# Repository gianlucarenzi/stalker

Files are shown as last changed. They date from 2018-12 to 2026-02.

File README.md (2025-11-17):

STm32-to-Amiga-Local-Keyboard adaptER
=====================================

The STALKER adapter board enables connecting USB HID keyboards to your Amiga 1000, Amiga 2000/3000, Amiga 4000/CD32, Amiga 500, Amiga 1200 and Amiga 600 and it is based upon 32-bit STM32 microcontroller.

The STALKER provides built-in USB stack which enables USB HID keyboards support without the need for installing additional AmigaOS software drivers. The whole installation process comes down to simply connecting a STALKER adapter and plug to the keyboard port of your Amiga 1000, 2000 or 4000 externally, or internally in any other Amiga computers.

Additional feature of the adapter is its „Bootloader” function allowing future firmware upgrades.
The STALKER comes with dedicated firmware, but it can be easily installed any firmware version as it's an open source project.

Features
========

* supports for both USB HID, wireless adapters and USB-PS/2 keyboards,
* Amiga 1000, 2000/3000, Amiga 4000/CD32, Amiga 1200, Amiga 600 and Amiga 500 compatibility,
* built-in USB stack with HID Keyboard firmware driver
* "Bootloader" function allowing future firmware upgrades,
* "Status" indicator LED providing information about device's state,
* built around 32-bit STM32 microcontroller utilizing latest technology,
* non-blocking keyboard.

Why so a bad name for a so good product?

As stated in the title, the STALKER is an acronym of:

STm32-to-Amiga-Local-Keyboard adaptER
-------------------------------------

But if you think a little more, it is catching all the keystrokes you do,

so basically it is stalking you! ;-)

Rendered Images
---------------
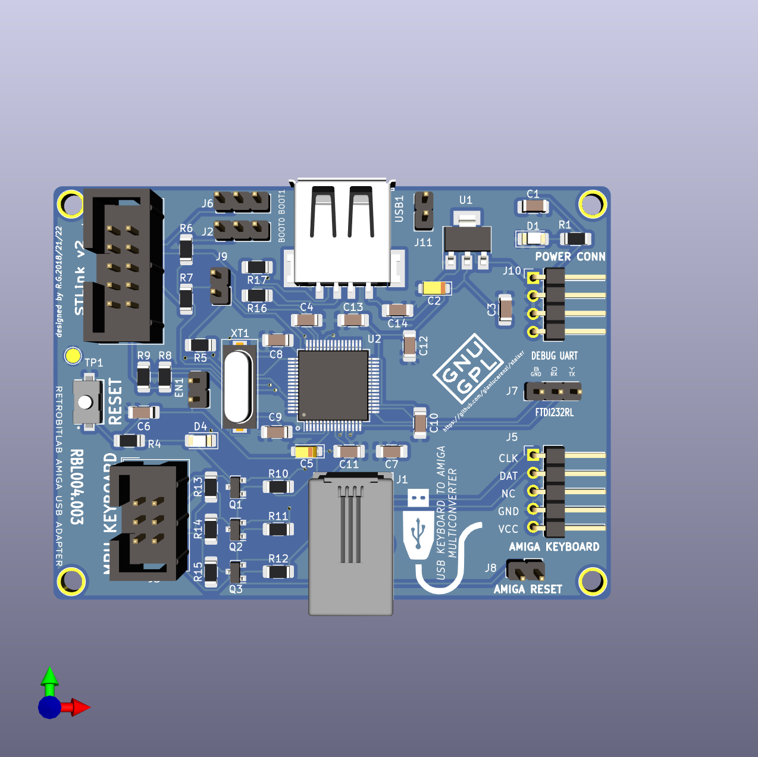
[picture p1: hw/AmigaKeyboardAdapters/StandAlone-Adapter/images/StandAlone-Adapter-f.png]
Board Front

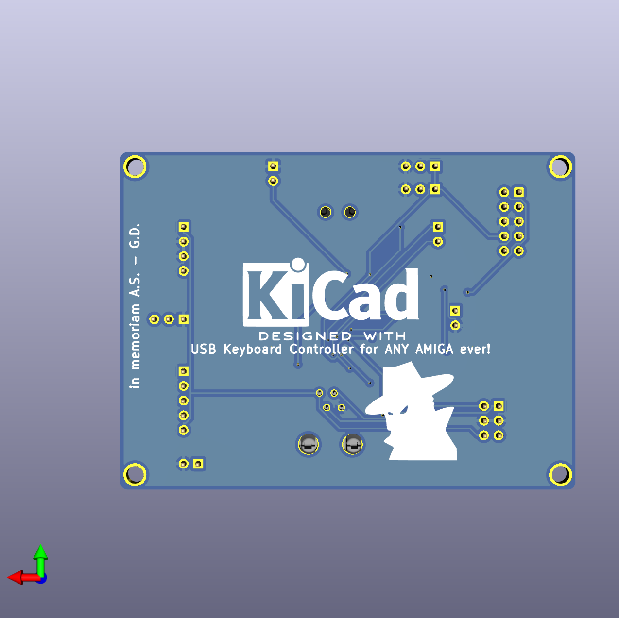
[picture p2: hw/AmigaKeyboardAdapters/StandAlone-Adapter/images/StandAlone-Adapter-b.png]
Board Back

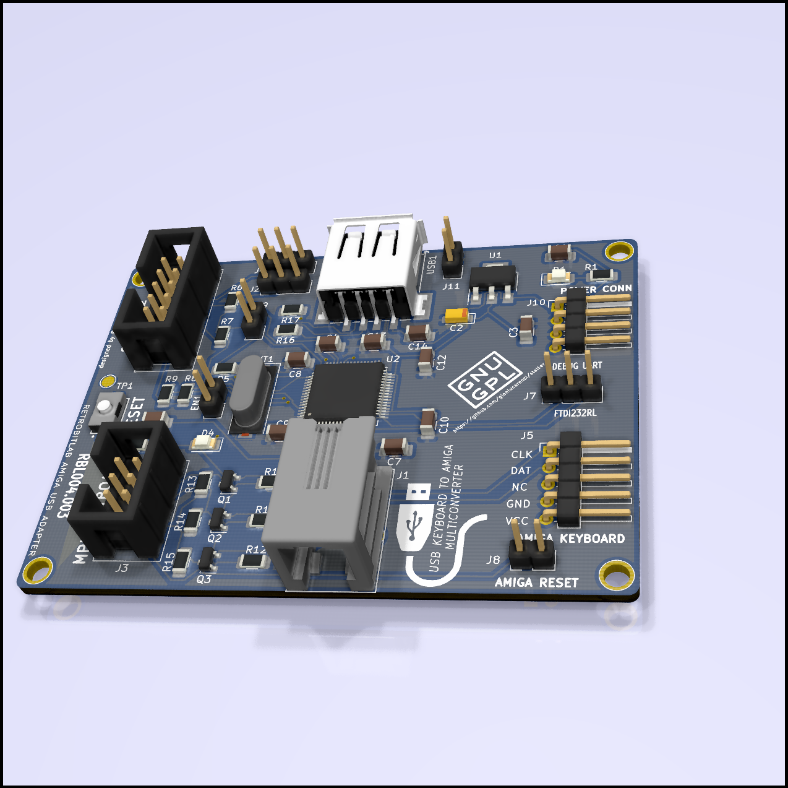
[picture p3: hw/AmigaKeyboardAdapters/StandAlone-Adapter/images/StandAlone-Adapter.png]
Board Overall


Upgrading with Linux and OpenOCD and STLinkV2 Programmer/Debugger
-----------------------------------------------------------------
Starting from this project folder, there are some shell scripts
that can be used to program the board if you unluckly brick it or simply to upgrade
some features from bootloader and application without using the STM32CubeProgrammer software.

Connect the [STLinkV2 jtag/swd programmer](https://it.aliexpress.com/item/1005005293861493.html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)
to the STALKER Board in J4 connector (STLink V2 in the silkscreen) using a standard 10 pin IDC female/female [cable 2x5 10P](https://it.aliexpress.com/item/1005003161799870.html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).
Opening the project folder, you can compile all projects (application and bootloader) running:
```
make clean
make
```
and then launch the corresponding script:

* bootloader.sh (to erase all the flash memory and program the bootloader)

* flash.sh (to program the application, after having erased all needed flash sectors)

Upgrading quick guide
---------------------
First, get your own copy of STM32CubeProgrammer software.
It is free to use, please checkout the STMicroElectronics web site and install it into your PC.
Please have a look at the following web link: https://www.st.com/en/development-tools/stm32cubeprog.html

After launched it will be shown as the following image.



Connect the <b>special upgrade cable</b> to the right lower opening of <b>The STALKER</b>, then connect the board with the provided USB cable to the one of the USB ports available in your computer. The red LED will light steady.

Then click on the connect button on the upper right position of the STM32Cube Programmer's window as shown in the picture below:

pic1-connect

Some information will be shown into the right bottom side of the same window, plus the memory locations will be filled up by the programmed values.

pic2-connected

After, you will need to select the correct <b>FIRMWARE</b> file (<b>.hex file format</b>) clicking into the <b>Open File</b> tab button like in the following example:

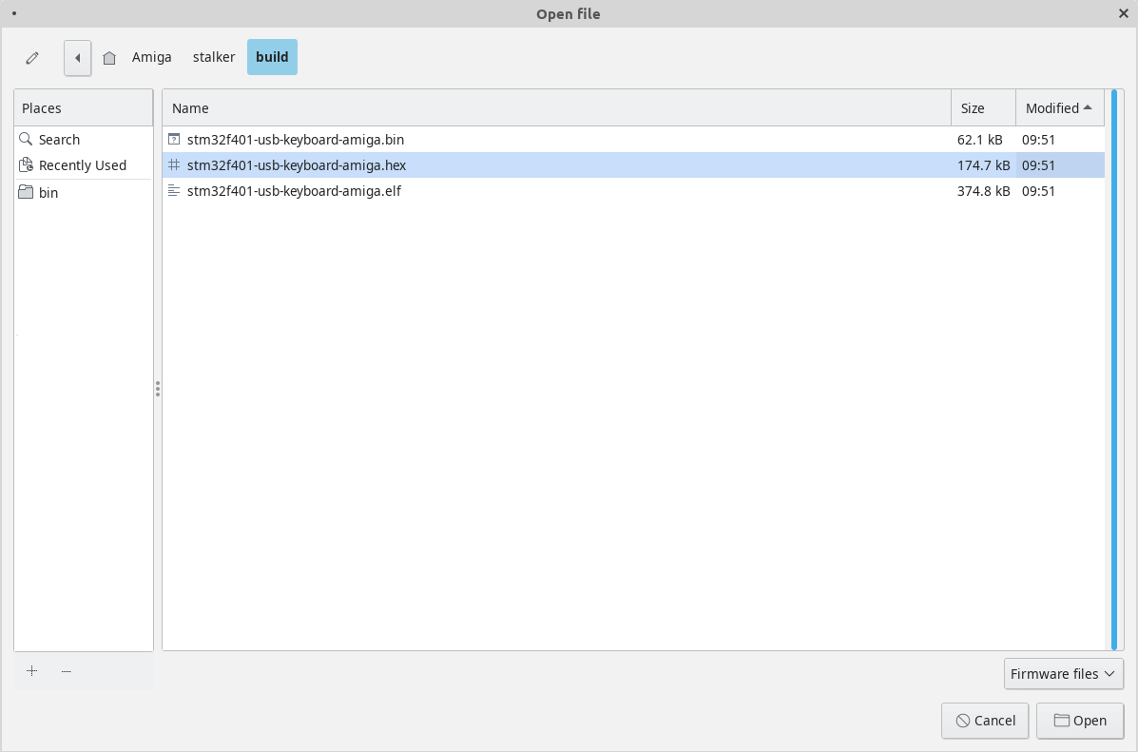
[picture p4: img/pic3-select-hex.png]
pic3-select-hex


If the file is loaded correctly, the <b>Download button</b> needs to be pressed to start the programming/flashing procedure. It will takes few seconds to be completed.

pic4-download-flash

The firmware is correctly installed into the board, and it can be used as usual.

pic5-complete

Now you can:

* Disconnect the board from USB from your PC
* Remove the special ugrade cable
* Re-install the board into your Amiga Computer's setup.
* Connect a USB Keyboard, and turn on the Amiga Computer.

That's all folks!

Software & Hardware License
---------------------------
Copyright (C) 2018/2019/2022/2023/2025 Gianluca Renzi <gianlucarenzi@eurek.it> <icjtqr@gmail.com>

The hardware of this project is released as free/open hardware under the
GNU GPL v3 License terms. See licence.txt for details.

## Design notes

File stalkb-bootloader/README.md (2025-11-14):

# STM32 USB Bootloader

This project implements a simple USB bootloader for STM32F401xC microcontrollers. It allows for in-application firmware updates via USB.

## Features

*   **Custom Bootloader:** Provides a mechanism to jump to either the DFU (Device Firmware Upgrade) bootloader or a user application.
*   **Boot Mode Selection:** Determines whether to enter DFU mode or run the application based on a GPIO pin state.
*   **Application Validation:** Checks the validity of the application firmware before jumping to it.
*   **UART Output:** Provides informative messages via UART for debugging and status updates.

## Getting Started

These instructions will get you a copy of the project up and running on your local machine for development and testing purposes.

### Prerequisites

*   **ARM GCC Compiler:** You will need an ARM-none-eabi toolchain.
    *   For Debian/Ubuntu: `sudo apt-get install gcc-arm-none-eabi`
*   **Make:** Build automation tool.
    *   For Debian/Ubuntu: `sudo apt-get install make`
*   **STM32CubeIDE or equivalent:** For project configuration and initial code generation (though this project is already configured).

### Building the Project

To build the project, navigate to the root directory of the repository and run `make`:

```bash
make
```

This will generate the `.elf`, `.hex`, and `.bin` files in the `build/` directory.

### Flashing the Bootloader

The generated `.bin` or `.hex` file can be flashed to your STM32F401xC microcontroller using an ST-Link debugger or similar programming tool.

### Usage

1.  **Power on** your STM32F401xC board.
2.  The bootloader will check the state of the `BOOT_MODE_Pin` (configured in `main.c` and `MX_GPIO_Init`).
    *   If `BOOT_MODE_Pin` is **LOW**, the bootloader will jump to the **DFU Bootloader**.
    *   If `BOOT_MODE_Pin` is **HIGH**, the bootloader will attempt to jump to the **user application**.
3.  Ensure your user application is flashed at the correct address (defined by `__appflash_start` in the linker script).

## Project Structure

*   `Core/`: Contains application-specific source code and headers (`main.c`, `stm32f4xx_it.c`, etc.).
*   `Drivers/`: Contains STM32 HAL drivers and CMSIS files.
*   `STM32F401XX_FLASH.ld`: Linker script for the STM32F401xC.
*   `Makefile`: Build script for the project.
*   `startup_stm32f401xc.s`: Startup assembly file.

## Contributing

Feel free to fork the repository, open issues, or submit pull requests.

## License

This project is licensed under the terms found in the `LICENSE` file in the root directory of this software component.

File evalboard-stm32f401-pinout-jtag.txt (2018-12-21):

EVALBOARD ARMJTAG PINOUT
------------------------

HEADER_CONN_2X10

1  +3v3       2   +3v3
3  nTRST      4   GND
5  TDI        6   GND
7  TMS/SWDIO  8   GND
9  TCK/SWCLK  10  GND
11 NC         12  GND
13 TDO        14  GND
15 nRST       16  GND
17 NC         18  GND
19 NC         20  GND

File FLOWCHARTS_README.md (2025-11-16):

# Project Flowcharts - USB to Amiga Keyboard Adapter

Questo documento descrive i diagrammi di flusso del progetto **USB to Amiga Keyboard Adapter** basato su FreeRTOS.

## 📊 Diagrammi Disponibili

### 1. **Project Flowchart** (`project_flowchart.svg/png`)
**Panoramica generale dell'architettura del progetto**

- **Scopo**: Mostra la struttura generale del sistema con tutti i componenti principali
- **Livelli mostrati**:
  - Hardware Layer (USB Keyboard, STM32F401, Amiga Computer)
  - FreeRTOS Kernel (Scheduler, Code)
  - Application Tasks (USB Task, Amiga Task)
  - Hardware Abstraction Layer (Driver STM32)
  - System Initialization (main, init)

### 2. **Detailed Architecture** (`detailed_architecture.svg/png`)
**Architettura dettagliata con flusso dati**

- **Scopo**: Mostra il flusso dettagliato dei dati tra i componenti
- **Dettagli inclusi**:
  - Strutture dati (keyboard_message_t, led_message_t)
  - Timing dei task (10ms per tutti i task principali)
  - Priorità dei task (USB=Normal, Amiga=Low, LedManager=Low)
  - Dettagli del protocollo Amiga
  - Dimensioni delle code FreeRTOS

### 3. **Timing Flow** (`timing_flow.svg/png`)
**Flusso temporale delle operazioni**

- **Scopo**: Mostra la sequenza temporale delle operazioni del sistema
- **Sezioni**:
  - Sequenza di startup del sistema
  - Cicli runtime dei task
  - Timing del protocollo Amiga (livello microsecondo)
  - Gestione degli errori
  - Annotazioni temporali precise

## 🎯 **Architettura FreeRTOS**

### **Task Principali**

| Task | Priorità | Ciclo | Stack | Responsabilità |
|---|---|---|---|---|
| **USB Task** | Normal | 10ms | 1024 | USB HID, LED, Stato connessione |
| **Amiga Task** | Low | 10ms | 1024 | GPIO, Protocollo Amiga, Reset |
| **LedManagerTask** | Low | Event-Driven | 512 | Gestione LED di stato onboard |

### **Comunicazione Inter-Task**

| Coda | Dimensione | Direzione | Contenuto |
|---|---|---|---|
| **keyboardQueue** | 16 messaggi | USB → Amiga | keyboard_message_t |
| **ledQueue** | 16 messaggi | Amiga → USB | led_message_t |
| **ledManagerQueue**| 32 messaggi | USB → LedManager| led_manager_message_t |
| **amigaTaskQueue** | 8 messaggi | All → Amiga | AmigaTaskMsg_t |

### **Timing Critici**

| Operazione | Timing | Descrizione |
|---|---|---|
| **USB Task Cycle** | 10ms | Ciclo principale USB task |
| **Amiga Task Cycle** | 10ms | Ciclo principale Amiga task |
| **Clock Pulse** | 20μs | Durata impulso clock Amiga |
| **Handshake** | 85μs | Impulso handshake CPU Amiga |
| **Reset Detection** | 500ms | Timeout per rilevamento reset |

## 🔧 **Protocollo Amiga**

### **Caratteristiche Principali**
- **Ordine bit**: 6-5-4-3-2-1-0-7 (bit 7 = flag up/down)
- **Logica invertita**: 0 = HIGH (5V), 1 = LOW (0V)
- **Velocità**: ~17 kbits/sec (60μs per bit)
- **Handshake**: Obbligatorio impulso 85μs da CPU

### **Sequenza Trasmissione**
1. Setup data line (20μs)
2. Clock pulse LOW (20μs)
3. Clock pulse HIGH (20μs)
4. Ripeti per 8 bit
5. Attendi handshake CPU (85μs)

## 🚀 **Flusso di Esecuzione**

### **Startup Sequence**
1. `HAL_Init()` - Inizializzazione HAL
2. `SystemClock_Config()` - Configurazione clock
3. `MX_GPIO_Init()` - Inizializzazione GPIO
4. `MX_USART2_UART_Init()` - Inizializzazione UART debug
5. `create_tasks_and_queues()` - Creazione task e code
6. `vTaskStartScheduler()` - Avvio scheduler FreeRTOS

### **Runtime Operation**
- **USB Task**: Gestisce USB HID e LED ogni 10ms
- **Amiga Task**: Processa tastiera e gestisce reset ogni 10ms
- **Comunicazione**: Via code FreeRTOS thread-safe

## 📁 **File Generati**

```
project_flowchart.dot       # Sorgente Graphviz - Panoramica generale
project_flowchart.svg       # Diagramma SVG - Panoramica generale  
project_flowchart.png       # Diagramma PNG - Panoramica generale

detailed_architecture.dot   # Sorgente Graphviz - Architettura dettagliata
detailed_architecture.svg   # Diagramma SVG - Architettura dettagliata
detailed_architecture.png   # Diagramma PNG - Architettura dettagliata

timing_flow.dot             # Sorgente Graphviz - Flusso temporale
timing_flow.svg             # Diagramma SVG - Flusso temporale
timing_flow.png             # Diagramma PNG - Flusso temporale
```

## 🛠️ **Rigenerazione Diagrammi**

Per rigenerare i diagrammi:

```bash
# SVG (vettoriale)
dot -Tsvg project_flowchart.dot -o project_flowchart.svg
dot -Tsvg detailed_architecture.dot -o detailed_architecture.svg  
dot -Tsvg timing_flow.dot -o timing_flow.svg

# PNG (alta risoluzione)
dot -Tpng project_flowchart.dot -o project_flowchart.png -Gdpi=300
dot -Tpng detailed_architecture.dot -o detailed_architecture.png -Gdpi=300
dot -Tpng timing_flow.dot -o timing_flow.png -Gdpi=300
```

## 📋 **Note**

- I diagrammi sono ottimizzati per la documentazione tecnica
- I colori identificano i diversi livelli architetturali
- Le frecce tratteggiate indicano connessioni hardware
- Le frecce punteggiate indicano timing/cicli
- I diagrammi sono scalabili (formato SVG disponibile)

---
**Generato automaticamente per il progetto USB to Amiga Keyboard Adapter v3.0NG-RTOS**

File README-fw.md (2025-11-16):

# StalkerNG - Amiga Keyboard Interface Firmware

## Project Overview

This project provides firmware for an STM32F401xC microcontroller, designed to bridge modern USB keyboards with classic Amiga computers. It acts as an intelligent interface, translating standard USB Human Interface Device (HID) keyboard inputs into the specific Amiga keyboard protocol. This enables Amiga users to utilize a wide range of contemporary USB keyboards with their vintage systems, enhancing usability without compromising the authentic Amiga experience.

The firmware incorporates advanced features such as dynamic mode switching between Amiga and PC keyboard layouts, comprehensive LED status management (Caps Lock, Num Lock, Scroll Lock), and robust system reset functionalities triggered by specific key combinations or Amiga hardware signals. Built upon the FreeRTOS real-time operating system, it ensures efficient and concurrent management of all tasks, from USB communication to Amiga protocol handling and persistent settings storage.

## Features

*   **Firmware Version:** `v3.0NG-RTOS`
*   **USB HID Keyboard Host:** Full support for connecting and interpreting inputs from standard USB HID keyboards.
*   **Amiga Keyboard Protocol Translation:** Seamless conversion of USB keyboard events into the native Amiga keyboard protocol.
*   **Dynamic Mode Switching:** Toggle between Amiga and PC keyboard layouts using a dedicated key combination (`Left Control + Left Alt + Left Shift + P`). The selected mode is persistently stored in EEPROM.
*   **LED Status Synchronization:** Synchronizes Caps Lock, Num Lock, and Scroll Lock LED states between the USB keyboard and the Amiga system.
*   **System Reset Functionality:**
    *   **PC Mode Reset:** Triggered by holding `Control + Alt + Delete` for 500ms.
    *   **Amiga Mode Reset:** Triggered by holding `Left Control + Left GUI + (Right GUI or Application Key)` for 500ms.
    *   Supports hardware-initiated resets from the Amiga side.
*   **Persistent Settings:** Utilizes internal EEPROM (or Flash emulation) for storing user preferences, such as the last selected operating mode.
*   **Real-Time Operating System (RTOS):** Leverages FreeRTOS for efficient multi-tasking, ensuring responsive and reliable operation.
*   **Easter Egg:** If no keyboard is connected, the firmware will periodically type out a message on the Amiga. This feature is enabled by a compile-time flag.

## Hardware Requirements

*   **Microcontroller:** STM32F401xC (or any compatible STM32F4 series board with USB Host capabilities).
*   **USB Host Port:** Required for connecting USB keyboards.
*   **Amiga Interface Circuitry:** Custom hardware interface to connect the microcontroller to the Amiga keyboard port.

## Software Architecture

The firmware is structured around the STM32Cube HAL and FreeRTOS, providing a robust and modular foundation. A multi-tasking paradigm is employed to manage various functionalities concurrently, ensuring high responsiveness and system stability.

*   **FreeRTOS:** The core of the concurrent execution, managing task scheduling, inter-task communication (via message queues), and precise timing.
*   **STM32 HAL Drivers:** Provides low-level access and control over the STM32 microcontroller's peripherals.
*   **USB Host Library:** Handles the complexities of USB communication, including device enumeration, configuration, and parsing of HID reports from connected keyboards.
*   **Amiga Keyboard Protocol Driver:** Implements the specific timing and data exchange required for communication with the Amiga computer, translating generic USB HID scancodes into Amiga-specific scancodes.
*   **EEPROM Driver:** Manages read and write operations to non-volatile memory, ensuring that user settings and configurations persist across power cycles.
*   **Inter-Task Communication:** Tasks communicate using thread-safe FreeRTOS queues:
    *   `keyboardQueueHandle`: Passes raw keyboard data from `usbTask` to `amigaTask`.
    *   `ledQueueHandle`: Passes LED status changes (Caps/Num/Scroll lock) from `amigaTask` to `usbTask`.
    *   `ledManagerQueueHandle`: Sends commands from `usbTask` to `led_manager_task` to control the onboard status LED.
    *   `amigaTaskQueueHandle`: Used for sending internal commands (like reset notifications) to the `amigaTask` itself.

## Key Components (FreeRTOS Tasks)

The firmware is organized into several FreeRTOS tasks, each responsible for a specific aspect of the system:

### `amigaTask`

This task is the central hub for Amiga-related keyboard logic. Its priority is `osPriorityLow`.

*   **Initialization:** Sets up the Amiga keyboard interface and reads the initial operating mode from EEPROM.
*   **Mode Management:** Determines and sets the `current_mode` (AMIGA_MODE or PC_MODE) based on saved settings or defaults.
*   **Event Processing:** Receives `keyboard_message_t` events from the `usbTask` via `keyboardQueueHandle`.
*   **Protocol Translation:** Converts received USB HID data into the Amiga keyboard protocol and sends it to the Amiga via `amikb_process()`.
*   **Mode Switching:** Detects and acts upon the `Left Control + Left Alt + Left Shift + P` key combination to toggle operating modes.
*   **System Reset Handling:** Monitors for specific key combinations (`Control + Alt + Delete` in PC mode, `Left Control + Left GUI + (Right GUI or Application Key)` in Amiga mode) and Amiga hardware reset signals, initiating a system reset if conditions are met.
*   **LED Feedback:** Sends `led_status_t` updates to the `ledQueueHandle` for visual feedback.

#### `amigaTask` Main Loop Flowchart

```mermaid
graph TD
    A[Start amigaTask] --> B{Initialize Amiga Interface};
    B --> C{Read Mode from EEPROM};
    C --> D{Set current_mode};
    D --> E[amiga_task_init()];
    E --> F[Loop Forever];
    F --> G{osMessageQueueGet(keyboardQueueHandle, msg, 0)};
    G -- osOK --> H{process_keyboard_message(msg)};
    H --> I{convert_message_to_keyboard_code(msg, code)};
    I --> J{amikb_process(code)};
    J --> K{Check if Amiga Interface is ready};
    K -- Not Ready --> L[Set amiga_ready = 1; amikb_ready(1)];
    L --> M{osMessageQueueGet(amigaTaskQueueHandle, internal_msg, 0)};
    G -- Not osOK --> M;
    M -- osOK (RESET_START) --> N[Send LED_RESET_BLINK to ledQueue];
    N --> O[check_for_special_combos()];
    M -- Not osOK --> O;
    O --> P[amiga_task_check_reset_condition()];
    P --> Q[osDelay(10ms)];
    Q --> F;
```

**Timing Considerations for `amigaTask`:**
*   `osMessageQueueGet(keyboardQueueHandle, ..., 0)`: This is a non-blocking call, ensuring the task doesn't halt waiting for keyboard input. Keyboard events are processed as soon as they are available.
*   `osMessageQueueGet(amigaTaskQueueHandle, ..., 0)`: Also non-blocking, for internal task communication.
*   `osDelay(10ms)`: A small delay introduced at the end of the loop to yield CPU time to other tasks and prevent busy-waiting. This results in a cycle time of approximately 10ms.
*   `check_for_special_combos()` and `amiga_task_check_reset_condition()`: Both functions incorporate internal timers (e.g., `RESET_TIMEOUT_MS` of 500ms) to detect sustained key presses or Amiga clock line states, preventing spurious triggers.

### `usbTask`

Responsible for all USB Host related operations, primarily interacting with USB keyboards. Its priority is `osPriorityNormal`.

*   **USB Host Management:** Initializes and manages the USB Host stack.
*   **Device Detection:** Monitors for the connection and disconnection of USB keyboards.
*   **HID Report Processing:** Reads raw HID reports from connected keyboards, sending an update only when the state changes.
*   **Event Generation:** Parses HID data into a structured `keyboard_message_t` format.
*   **Inter-Task Communication:** Sends processed keyboard messages to the `amigaTask` via `keyboardQueueHandle`.
*   **LED Control:** Receives `led_status_t` commands from the `amigaTask` and controls the LEDs on the connected USB keyboard (e.g., Caps Lock, Num Lock).

#### `usbTask` Main Loop Flowchart (Conceptual)

```mermaid
graph TD
    A[Start usbTask] --> B{Initialize USB Host};
    B --> C[Loop Forever];
    C --> D{USBH_Process()};
    D --> E{Check for USB Keyboard State Changes};
    E -- Connected --> F{Read HID Report};
    F --> G{Parse HID Data & Check for Changes};
    G -- State Changed --> H{Create keyboard_message_t};
    H --> I{osMessageQueuePut(keyboardQueueHandle, msg, 0)};
    I --> J{Check for LED Status Messages};
    J -- osOK --> K{Control USB Keyboard LEDs};
    K --> C;
    J -- Not osOK --> C;
    G -- No Change --> J;
    E -- Disconnected --> L[Send Reset Event to amigaTask];
    L --> C;
```

**Timing Considerations for `usbTask`:**
*   `USBH_Process()`: This function is the core of the USB host stack and is called in a loop.
*   `osDelay(10ms)`: The task loop has a 10ms delay, making it responsive to USB events and LED control messages.
*   HID Report Polling: The frequency of reading HID reports is often dictated by the USB HID descriptor of the connected keyboard (e.g., 8ms, 10ms). The `usbTask`'s loop is fast enough to accommodate this polling rate.
*   `osMessageQueuePut(keyboardQueueHandle, msg, 0, 0)`: A non-blocking call to send keyboard events, ensuring the `usbTask` doesn't block if the `amigaTask` queue is temporarily full.

### `eeprom_task`

Manages non-volatile storage operations.

*   **Persistence:** Handles asynchronous read and write requests for system settings (e.g., `current_mode`) to the internal EEPROM (emulated in Flash).
*   **Reliability:** Ensures data integrity during storage operations.

### `led_manager_task`

Controls the onboard status LED for visual feedback. Its priority is `osPriorityLow`.

*   **LED Control:** Receives commands via `ledManagerQueueHandle` from other tasks (like `usbTask`) and manages the state of the single onboard LED to reflect system status (e.g., solid ON for ready, blinking for waiting).

### `log_task`

Handles system logging and debugging output.

*   **Debug Output:** Processes and outputs debug messages generated by other tasks, typically via a UART interface to a connected terminal or debug probe. It is initialized at startup but does not run as a separate task.

## Build Instructions

The project uses a standard GNU Make-based build system.

1.  **Toolchain:** Ensure you have the `arm-none-eabi-gcc` toolchain installed and configured in your system's PATH.
2.  **Navigate:** Open a terminal and navigate to the root directory of this project.
3.  **Clean Build:** To remove all previously compiled files and artifacts, execute:
    ```bash
    make clean
    ```
4.  **Build Firmware:** To compile the source code and link the final firmware image, execute:
    ```bash
    make
    ```
5.  **Output:** Upon successful compilation, the following files will be generated in the `build/` directory:
    *   `StalkerNG.elf`: Executable and Linkable Format (ELF) file, containing debugging information.
    *   `StalkerNG.hex`: Intel HEX format file, commonly used for flashing.
    *   `StalkerNG.bin`: Raw binary image, also suitable for flashing.

## Usage and Operation

1.  **Flash Firmware:** Program the `StalkerNG.bin` file onto your STM32F401xC development board using your preferred flashing tool (e.g., STM32CubeProgrammer, OpenOCD).
2.  **Connect USB Keyboard:** Plug your USB keyboard into the USB Host port on the STM32 board.
3.  **Connect to Amiga:** Connect the custom Amiga interface from your STM32 board to the keyboard port of your Amiga computer.
4.  **Power On:** Power on your STM32 board and Amiga.

### Mode Switching

The firmware supports two operating modes: Amiga Mode and PC Mode.

*   **Toggle Mode:** Press and hold the key combination `Left Control + Left Alt + Left Shift + P`. The mode will toggle between AMIGA_MODE and PC_MODE.
*   **Persistence:** The selected mode is automatically saved to the internal EEPROM and will be restored on subsequent power-ups.

### System Reset

The firmware provides multiple ways to trigger a system reset for the Amiga.

*   **PC Mode Reset:** While in PC Mode, press and hold `Control + Alt + Delete` for approximately 500 milliseconds.
*   **Amiga Mode Reset:** While in Amiga Mode, press and hold `Left Control + Left GUI + (Right GUI or Application Key)` for approximately 500 milliseconds.
*   **Amiga Hardware Reset:** The firmware also detects and responds to a hardware-initiated reset signal from the Amiga computer itself.

### USB Keyboard Compatibility

It is crucial to understand that **not all USB keyboards are compatible** with this firmware. The compatibility depends on how the keyboard communicates its key presses to the host.

This firmware, due to limitations in the underlying STM32 USB Host HID drivers, primarily supports keyboards that operate using the **USB HID Boot Protocol**. This protocol is a simplified subset of the full HID specification, designed to provide basic keyboard (and mouse) functionality even before a full operating system driver is loaded.

Keyboards that rely on the more complex **USB HID Report Protocol** for their functionality (especially those with advanced features, custom layouts, or extensive multimedia keys) are generally **not supported**. The firmware's current HID implementation is not adequate to fully interpret these custom report descriptors.

**What to look for in a compatible keyboard:**

*   **Basic Functionality:** Keyboards designed for general office use or older systems are more likely to implement the Boot Protocol.
*   **Simplicity:** Keyboards without extensive programmable keys, RGB lighting, or complex multimedia functions beyond standard volume/play controls might be more compatible.
*   **Testing is Key:** The best way to determine compatibility is often to test the keyboard with the firmware.

**Known Compatible Example:**

*   **Logitech Wireless Keyboards with Unifying Receiver (e.g., VID 0x046d, PID 0xc534):** Many Logitech wireless keyboard/mouse combinations that use the Unifying Receiver dongle operate in USB BOOT mode for basic functionality.
    *   **Note:** While the basic alphanumeric and modifier keys typically work, **multimedia keys** (e.g., volume, play/pause) on such keyboards are often implemented using the HID Report Protocol and may **not be recognized** by this firmware.

We recommend users to prioritize keyboards known for their basic, robust USB HID compliance. If a keyboard does not work, it is likely due to its reliance on the USB HID Report Protocol.

## Contributing

Contributions are welcome! If you find a bug or have an enhancement in mind, please open an issue or submit a pull request.

## License

This project is licensed under the terms found in the `LICENSE` file in the root directory of this repository.

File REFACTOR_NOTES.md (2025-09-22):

# FreeRTOS Refactor - USB to Amiga Keyboard Adapter

## Overview

This document describes the refactoring of the USB to Amiga keyboard adapter project to use FreeRTOS with two separate tasks for better separation of concerns and improved real-time performance.

## Architecture Changes

### Before Refactor
- Single main loop handling both USB and Amiga communication
- Blocking operations and polling-based approach
- Tight coupling between USB and Amiga logic

### After Refactor
- Two separate FreeRTOS tasks:
  - **usb_task**: Handles USB HID protocol and LED management
  - **amiga_task**: Handles GPIO communication with Amiga and scancode processing
- Queue-based communication between tasks
- Non-blocking, event-driven architecture

## Task Structure

### USB Task (`usb_task`)
**Priority**: 3 (High)
**Stack Size**: 512 words (configMINIMAL_STACK_SIZE * 4)
**Responsibilities**:
- Initialize and manage USB Host
- Process USB HID events
- Handle keyboard connection/disconnection
- Read keyboard data from USB
- Manage USB keyboard LEDs
- Send keyboard data to Amiga task via queue
- Receive LED commands from Amiga task via queue

**Key Functions**:
- `usb_task()` - Main task function
- `usb_task_init()` - Task initialization
- `usb_keyboard_led_set()` - Set keyboard LED state
- `usb_keyboard_led_init_sequence()` - LED initialization sequence

### Amiga Task (`amiga_task`)
**Priority**: 2 (Medium)
**Stack Size**: 256 words (configMINIMAL_STACK_SIZE * 2)
**Responsibilities**:
- Initialize Amiga GPIO interface
- Process keyboard data from USB task
- Convert USB scancodes to Amiga scancodes
- Handle Amiga keyboard protocol timing
- Manage Amiga reset conditions
- Send LED status updates to USB task

**Key Functions**:
- `amiga_task()` - Main task function
- `amiga_task_init()` - Task initialization
- `amiga_task_handle_reset()` - Handle Amiga reset sequence

## Communication

### Queues
Two FreeRTOS queues handle inter-task communication:

1. **keyboard_queue** (USB → Amiga)
   - Size: 10 messages
   - Type: `keyboard_message_t`
   - Contains: keyboard data + timestamp

2. **led_queue** (Amiga → USB)
   - Size: 5 messages
   - Type: `led_message_t`
   - Contains: LED status + timestamp

### Message Structures
```c
typedef struct {
    keyboard_code_t keycode;
    uint32_t timestamp;
} keyboard_message_t;

typedef struct {
    led_status_t led_status;
    uint32_t timestamp;
} led_message_t;
```

## Files Added

### Header Files
- `inc/task_communication.h` - Common definitions for task communication
- `inc/usb_task.h` - USB task interface
- `inc/amiga_task.h` - Amiga task interface

### Source Files
- `src/usb_task.c` - USB task implementation
- `src/amiga_task.c` - Amiga task implementation

### Modified Files
- `src/main.c` - Refactored to create tasks and start scheduler
- `Makefile` - Added new source files

## Benefits of Refactor

1. **Separation of Concerns**: USB and Amiga logic are now completely separate
2. **Better Real-time Performance**: High-priority USB task ensures responsive USB handling
3. **Improved Maintainability**: Each task has a clear, focused responsibility
4. **Scalability**: Easy to add new features or modify individual components
5. **Debugging**: Easier to debug issues in specific subsystems
6. **Resource Management**: Better control over stack usage and CPU time

## Timing Considerations

- USB task runs at 10ms intervals for responsive USB handling
- Amiga task runs at 50ms intervals for reset condition checking
- Critical Amiga timing (20μs, 85μs) still uses hardware delays (udelay)
- FreeRTOS tick rate: 1ms (1000 Hz)

## Memory Usage

- **Total heap size**: 17KB (configTOTAL_HEAP_SIZE)
- **USB task stack**: ~2KB
- **Amiga task stack**: ~1KB
- **Queue memory**: ~500 bytes total
- **Remaining heap**: ~13.5KB for other allocations

## Configuration

Key FreeRTOS configuration parameters in `FreeRTOSConfig.h`:
- `configTICK_RATE_HZ`: 1000 (1ms tick)
- `configMAX_PRIORITIES`: 5
- `configTOTAL_HEAP_SIZE`: 17KB
- `configUSE_PREEMPTION`: 1 (preemptive scheduling)

## Future Enhancements

Possible future improvements:
1. Add watchdog task for system monitoring
2. Implement power management features
3. Add configuration task for runtime settings
4. Implement USB device detection improvements
5. Add statistics collection task

## Testing Notes

When testing the refactored code:
1. Verify USB keyboard detection and LED functionality
2. Test Amiga reset sequence
3. Check for proper task scheduling and no deadlocks
4. Verify timing-critical Amiga protocol operations
5. Test under various load conditions

## Compatibility

The refactored code maintains full compatibility with:
- Original hardware design
- Amiga keyboard protocol
- USB HID keyboard standard
- All existing features and Easter eggs

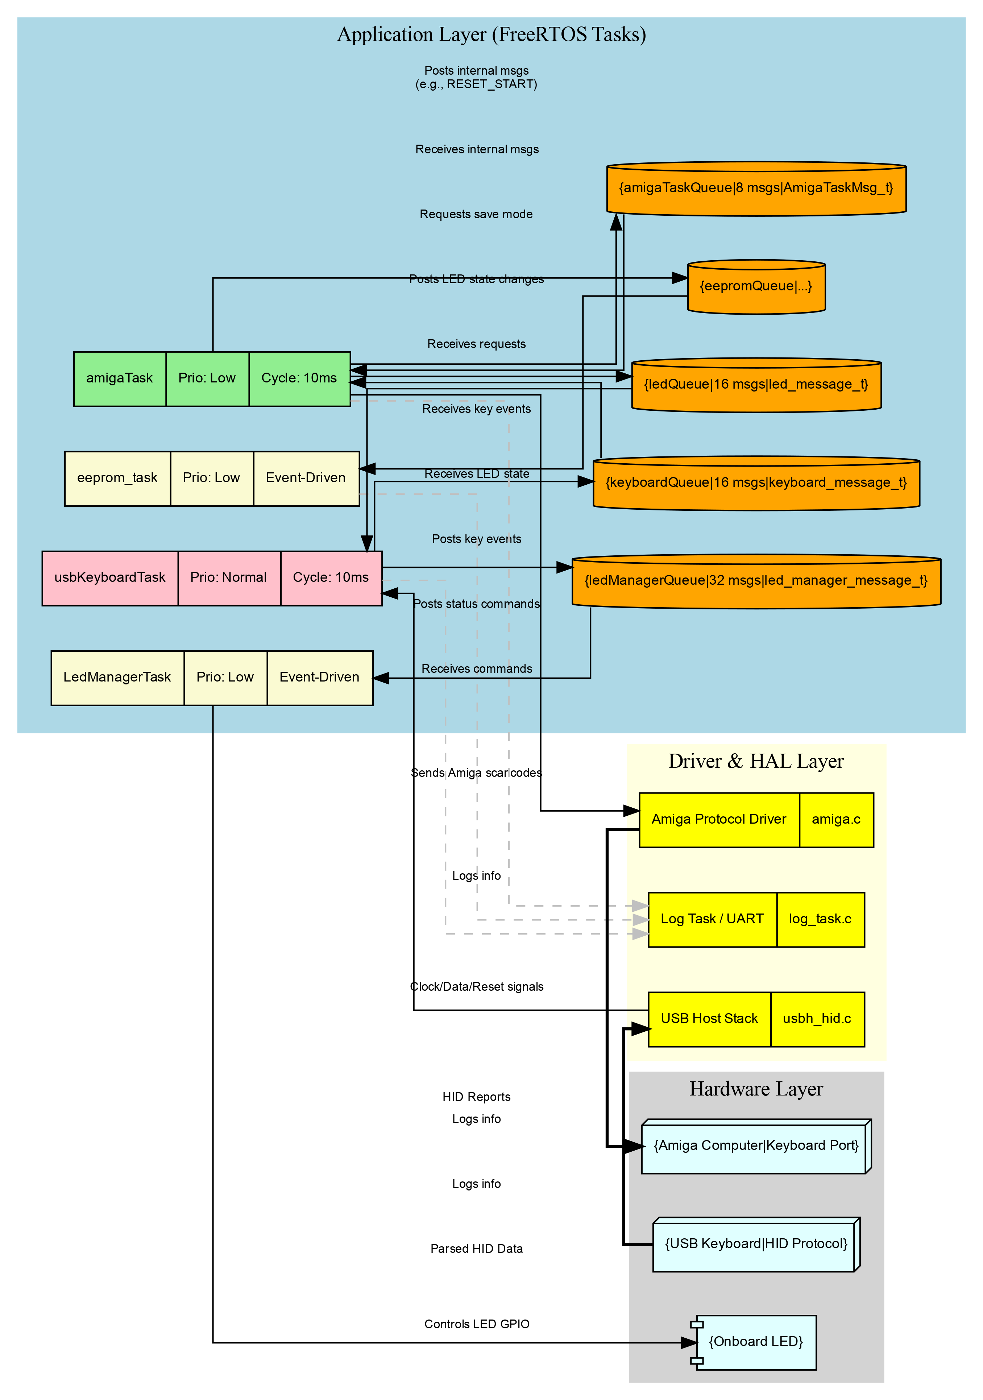
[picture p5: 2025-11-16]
detailed_architecture.png

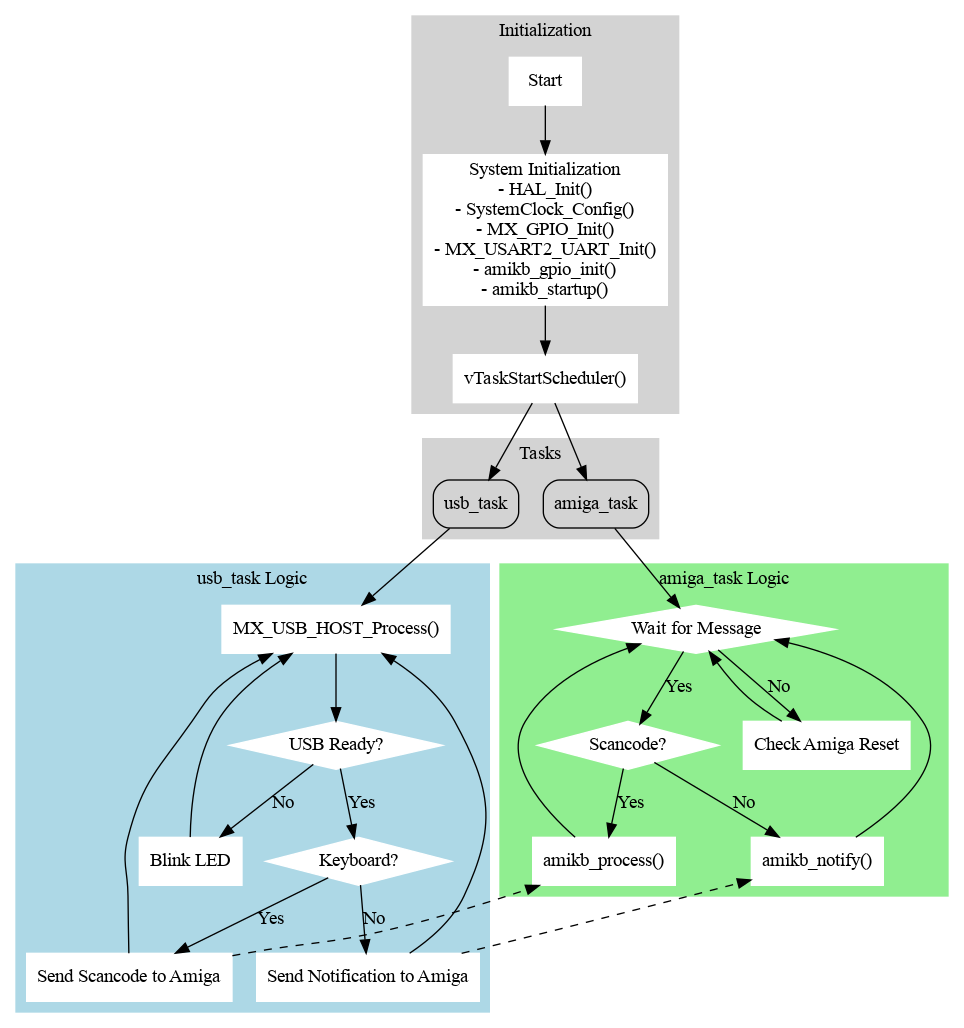
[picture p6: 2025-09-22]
flowchart.png

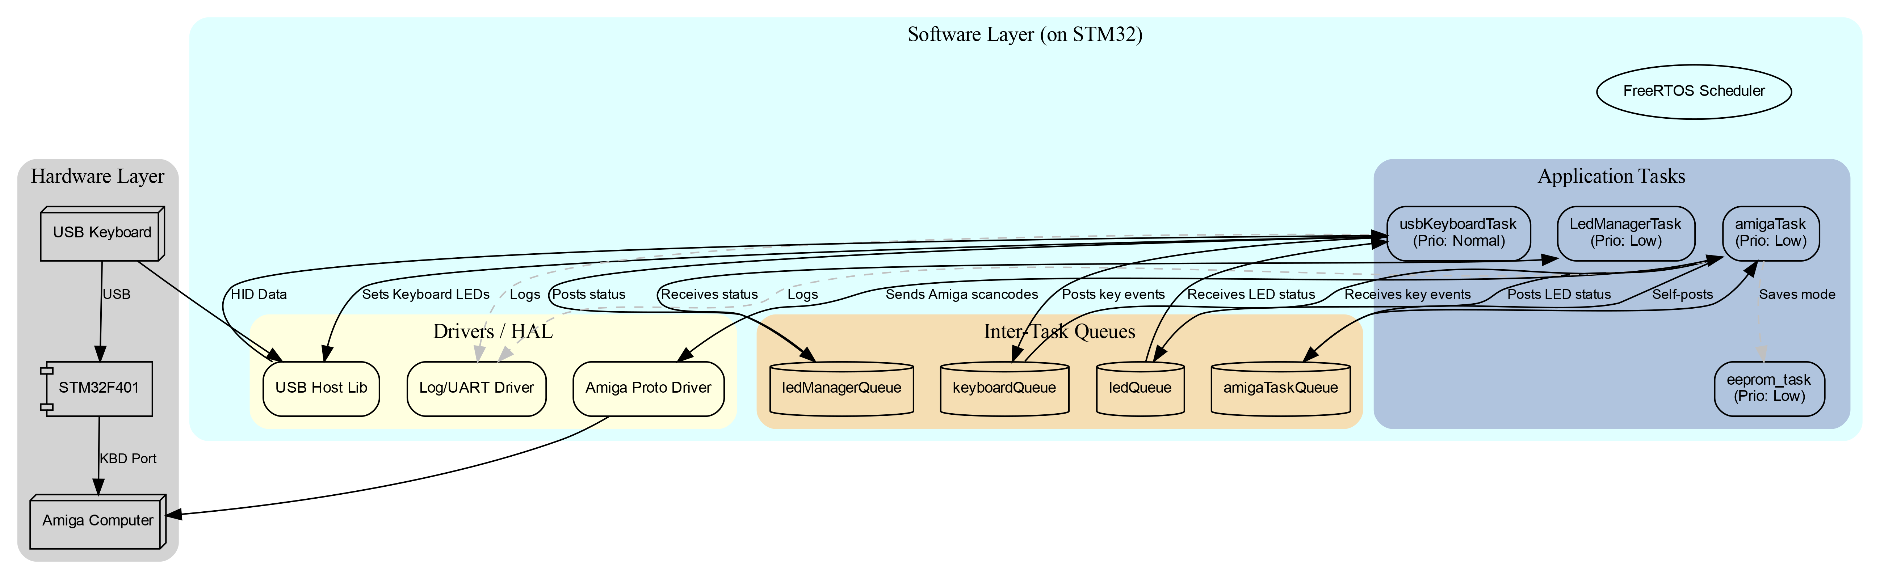
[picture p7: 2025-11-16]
project_flowchart.png

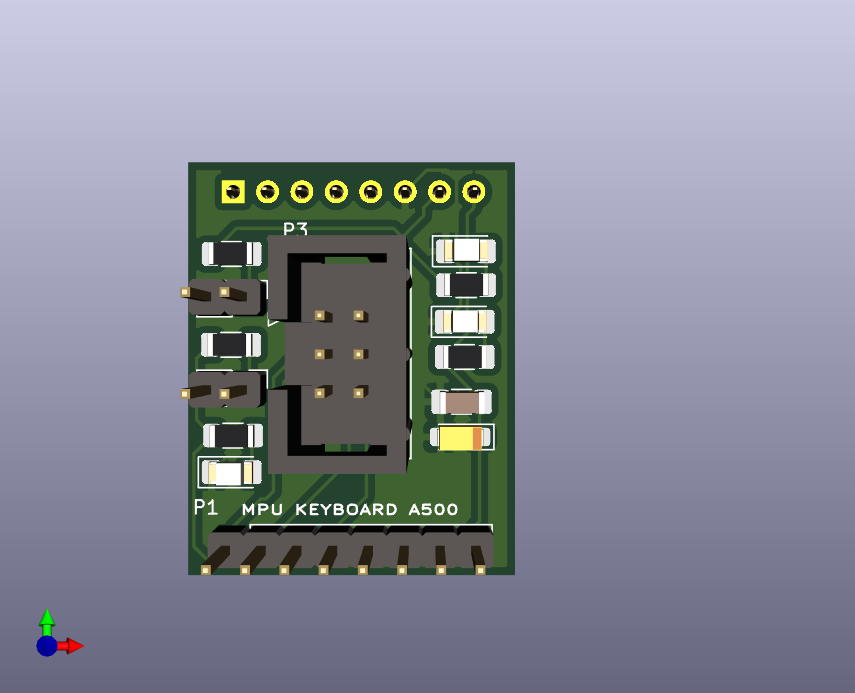
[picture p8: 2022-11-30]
hw/AmigaKeyboardAdapters/A500-Internal/images/A500MPU-Adapter-f.png

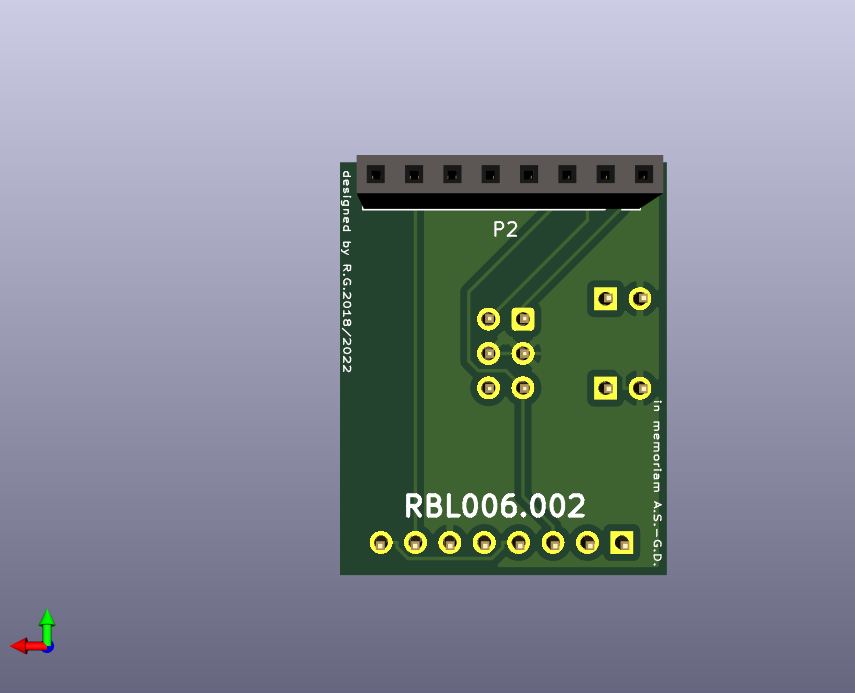
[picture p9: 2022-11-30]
hw/AmigaKeyboardAdapters/A500-Internal/images/A500MPU-Adapter-b.png

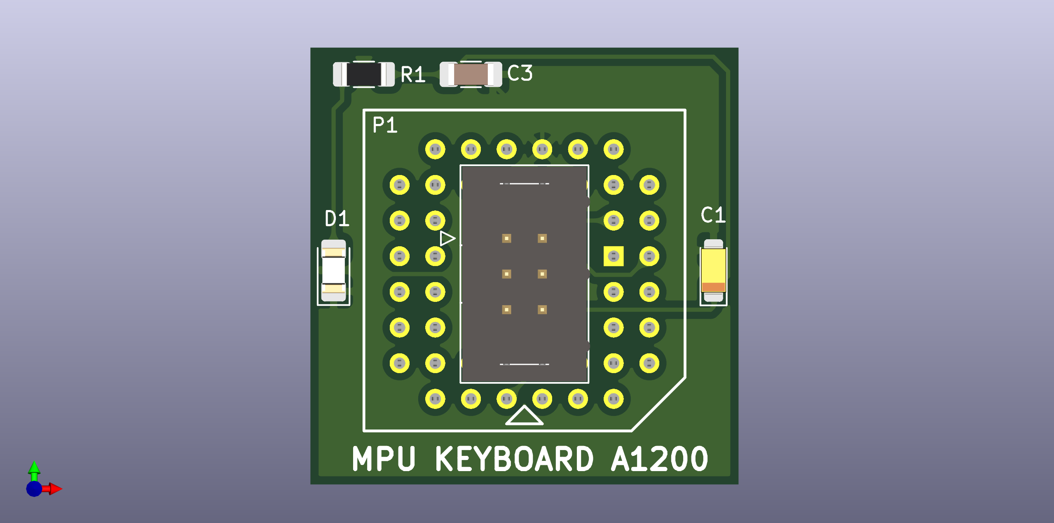
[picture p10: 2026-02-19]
hw/AmigaKeyboardAdapters/A1200-Internal/images/A1200MPU-Adapter-f.png

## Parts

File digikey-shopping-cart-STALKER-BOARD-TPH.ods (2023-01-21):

Quantità | Codice componente | Codice produttore | Descrizione | Riferimento cliente | Disponibile | Ordine arretrato | Prezzo unitario | Prezzo totale EUR
1 | 732-5394-ND | 61200621621 | CONN HEADER VERT 6POS 2.54MM |  | 1 | 0 | 0,45000 | 0,45
1 | AE10381-ND | A-2004-3-4-LP-N-R | CONN MOD JACK 4P4C R/A UNSHLD |  | 1 | 0 | 0,69000 | 0,69
5 | 881545-1-ND | 881545-1 | CONN SHUNT 2POS GOLD W/HANDLE |  | 5 | 0 | 0,27000 | 1,35
1 | 2057-PH1RB-05-UA-ND | PH1RB-05-UA | CONN HEADER R/A 5POS 2.54MM |  | 1 | 0 | 0,15000 | 0,15
1 | A97470-ND | 2-1761603-3 | CONN HEADER VERT 10POS 2.54MM |  | 1 | 0 | 4,35000 | 4,35
1 | 952-1902-ND | M20-9992046 | CONN HEADER VERT 20POS 2.54MM |  | 1 | 0 | 0,70000 | 0,70

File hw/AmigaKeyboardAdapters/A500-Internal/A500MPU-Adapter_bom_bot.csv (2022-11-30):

Comment | Designator | Footprint | LCSC Part #
Conn_01x08 | P2

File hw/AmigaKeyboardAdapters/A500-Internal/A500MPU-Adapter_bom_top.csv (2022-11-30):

Comment | Designator | Footprint | LCSC Part #
330R | R2 R3 R1 R4 R5 |  | C245520
100nF | C2 |  | C24497
10uF | C1 |  | C108529
Conn_02x03 | P3
Conn_01x08 | P1
Conn_01x02 | P4 P5
FLOPPY GREEN | D2 |  | C2980185
READY RED | D3 |  | C93133
POWER ORANGE | D1 |  | C183851

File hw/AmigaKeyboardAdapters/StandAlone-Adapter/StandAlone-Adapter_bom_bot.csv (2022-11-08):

Comment | Designator | Footprint | LCSC Part #
GPL | LOGO2
Stalker Logo | LOGO4

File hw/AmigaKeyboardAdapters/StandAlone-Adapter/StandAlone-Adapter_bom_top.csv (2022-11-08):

Id | Designator | Package | Quantity | Designation | Supplier and ref
1 | C2 | CP_EIA-3216-12_Kemet-S_Pad1.58x1.35mm_HandSolder | 1 | 10uF
2 | C3,C4,C6,C10,C11,C12,C13,C14 | C_1206_3216Metric_Pad1.33x1.80mm_HandSolder | 8 | 100n
3 | C5 | CP_EIA-3216-18_Kemet-A_Pad1.58x1.35mm_HandSolder | 1 | 10u
4 | C7 | C_1206_3216Metric_Pad1.33x1.80mm_HandSolder | 1 | 4.7uF
5 | C8,C9 | C_1206_3216Metric_Pad1.33x1.80mm_HandSolder | 2 | 22pF
6 | D1,D4 | LED_1206_3216Metric_Pad1.42x1.75mm_HandSolder | 2 | RED
7 | EN1 | PinHeader_1x02_P2.54mm_Vertical | 1 | CONN_01X02
8 | H1,H2,H3,H4 | MountingHole | 4 | CONN_01X01
9 | J1 | RJ10-RECEPTACLE-Assmann-ASS-2004-3-4-LP-N-R | 1 | RJ10
10 | J2,J6,J7 | PinHeader_1x03_P2.54mm_Vertical | 3 | Conn_01x03
11 | J3 | IDC-Header_2x03_P2.54mm_Vertical | 1 | Conn_02x03_Odd_Even
12 | J4,J10 | PinHeader_1x04_P2.54mm_Horizontal | 2 | Conn_01x04
13 | J5 | PinHeader_1x05_P2.54mm_Horizontal | 1 | Conn_01x05
14 | J8,J9,J11 | PinHeader_1x02_P2.54mm_Vertical | 3 | Conn_01x02
15 | Q1,Q2,Q3 | SOT-23 | 3 | BSS138
16 | R1,R5 | R_1206_3216Metric_Pad1.30x1.75mm_HandSolder | 2 | 330R
17 | R4,R6,R7,R8,R9,R10,R11,R12,R13,R14,R15 | R_1206_3216Metric_Pad1.30x1.75mm_HandSolder | 11 | 10K
18 | R16,R17 | R_1206_3216Metric_Pad1.30x1.75mm_HandSolder | 2 | 22R
19 | TP1 | TestPoint_Pad_D2.0mm | 1 | GND
20 | U1 | SOT-223 | 1 | AZ1117-3.3
21 | U2 | LQFP-64_10x10mm_P0.5mm | 1 | STM32F401RBTx
22 | LOGO1 | USB_PLUG_15x15mm | 1 | USB
23 | LOGO2 | KiCad-Logo2_12mm_SilkScreen | 1 | GPL
24 | LOGO3 | Symbol_GNU-GPL_SilkScreen_Small | 1 | STALKER!
25 | LOGO4 | Stalker_16.1x17.3mm | 1 | Stalker Logo
26 | C1 | C_1206_3216Metric_Pad1.33x1.80mm_HandSolder | 1 | 100nF
27 | RESET1 | SPST-7.3x3.9x2.5-WUERTH-434121025816 | 1 | SW_PUSH
28 | XT1 | Crystal_SMD_HC49-SD | 1 | 8Mhz
29 | USB1 | USB_A_M04P-F000_LCSC_C386738 | 1 | USB_A_SMD_LCSC

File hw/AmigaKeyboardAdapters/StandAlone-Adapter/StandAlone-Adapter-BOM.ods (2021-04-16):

Codice produttore | Produttore | Codice Digi-Key | Riferimento cliente | Designazione riferimento | Imballaggio | Stato componente | Quantità | Prezzo unitario | Prezzo totale | Quantità disponibile | Tempi standard produttore | Descrizione | Stato RoHS | Stato senza piombo | Stato del REACH
LM1117MP-3.3/NOPB | Texas Instruments | LM1117MP-3.3/NOPBCT-ND |  | U1 | Cut Tape (CT) | Active | 3 | 1,00000 | € 3,00 | 0 | 20 Settimane | IC REG LINEAR 3.3V 800MA SOT223 | A norma ROHS3 | Senza piombo | Non interessato da REACH
BSS138 | ON Semiconductor | BSS138CT-ND |  | Q1, Q2, Q3 | Cut Tape (CT) | Active | 9 | 0,23000 | € 2,07 | 0 | 52 Settimane | MOSFET N-CH 50V 220MA SOT23-3 | A norma ROHS3 | Senza piombo | Non interessato da REACH
A-2004-3-4-LP-N-R | Assmann WSW Components | AE10381-ND |  | J1 | Tray | Active | 3 | 0,48000 | € 1,44 | 28640 | 20 Settimane | CONN MOD JACK 4P4C R/A UNSHLD | A norma ROHS3 | Senza piombo | Non interessato da REACH
LTST-C150AKT | Lite-On Inc. | 160-1166-1-ND |  | D1, D2, D3 | Cut Tape (CT) | Active | 9 | 0,28000 | € 2,52 | 2788 | 20 Settimane | LED AMBER CLEAR SMD | A norma ROHS3 | Senza piombo | Non disponibile
LTST-C150TBKT | Lite-On Inc. | 160-1643-1-ND |  | D4 | Cut Tape (CT) | Active | 3 | 0,31000 | € 0,93 | 853 | 20 Settimane | LED BLUE CLEAR 1206 SMD | A norma ROHS3 | Senza piombo | Non disponibile
ERJ-8GEYJ152V | Panasonic Electronic Components | P1.5KECT-ND |  | R1, R2, R6, R13 | Cut Tape (CT) | Active | 12 | 0,05800 | € 0,69 | 115122 | 28 Settimane | RES SMD 1.5K OHM 5% 1/4W 1206 | A norma ROHS3 | Senza piombo | Non interessato da REACH
RMCF1206JT22K0 | Stackpole Electronics Inc | RMCF1206JT22K0CT-ND |  | R3 | Cut Tape (CT) | Active | 3 | 0,09000 | € 0,27 | 43983 | 21 Settimane | RES 22K OHM 5% 1/4W 1206 | A norma ROHS3 | Senza piombo | Non interessato da REACH
CRCW120610K0JNEAC | Vishay Dale | 541-4201-1-ND |  | R4, R5, R7, R8, R9, R10, R11, R12, R14, R15 | Cut Tape (CT) | Active | 30 | 0,06200 | € 1,86 | 24748 | 22 Settimane | RES 10K OHM 5% 1/4W 1206 | A norma ROHS3 | Senza piombo | Non disponibile
USB-A1HSW6 | On Shore Technology Inc. | ED2989-ND |  | USB1 | Tray | Active | 3 | 0,41000 | € 1,23 | 26104 | 14 Settimane | CONN RCPT TYPEA 4POS R/A | A norma ROHS3 | Senza piombo | Non interessato da REACH
FC4STCBMF8.0-BAG200 | Fox Electronics | 631-1100-ND |  | XT1 | Bulk | Active | 3 | 0,32000 | € 0,96 | 7581 | 18 Settimane | CRYSTAL 8.0000MHZ 20PF TH | A norma ROHS3 | Senza piombo | Non interessato da REACH
VJ1206Y104KXJPW1BC | Vishay Vitramon | 720-1803-1-ND |  | C3, C6, C7, C8, C9, C20, C12, C14 | Cut Tape (CT) | Active | 24 | 0,20200 | € 4,84 | 29832 | 19 Settimane | CAP CER 0.1UF 16V X7R 1206 | A norma ROHS3 | Senza piombo | Non disponibile
CL05C200JB5NNNC | Samsung Electro-Mechanics | 1276-1661-1-ND |  | C5, C4 | Cut Tape (CT) | Obsolete | 6 | 0,09000 | € 0,54 | 1807858 | 18 Settimane | CAP CER 20PF 50V C0G/NP0 0402 | A norma ROHS3 | Senza piombo | Non interessato da REACH
68016-220HLF | Amphenol ICC (FCI) | 609-3325-ND |  | TP1/1, USB_ID1, P1, EN1, DEBUG1, BOOT0, BOOT1,... | Bag | Active | 6 | 1,29000 | € 7,74 | 1905 | 8 Settimane | CONN HEADER R/A 20POS 2.54MM | A norma RoHS | Senza piombo | Non interessato da REACH
FSMSM | TE Connectivity ALCOSWITCH Switches | 450-1140-ND |  | RESET1 | Bulk | Active | 3 | 0,24000 | € 0,72 | 34637 | 13 Settimane | SWITCH TACTILE SPST-NO 0.05A 24V | A norma RoHS | Senza piombo | Non disponibile
61200621621 | Würth Elektronik | 732-5394-ND |  | J2 | Tray | Active | 3 | 0,38000 | € 1,14 | 5525 | 20 Settimane | CONN HEADER VERT 6POS 2.54MM | A norma ROHS3 | Senza piombo | Non interessato da REACH
C1206C475K8NACAUTO | KEMET | 399-12968-1-ND |  | C13 | Cut Tape (CT) | Active | 3 | 0,97000 | € 2,91 | 1468 | 24 Settimane | CAP CER 4.7UF 10V X8L 1206 | A norma ROHS3 | Senza piombo | Non interessato da REACH
RC1206JR-0712RL | Yageo | 311-12ERCT-ND |  | R16, R17 | Cut Tape (CT) | Active | 6 | 0,09000 | € 0,54 | 9181 | 20 Settimane | RES SMD 12 OHM 5% 1/4W 1206 | A norma ROHS3 | Senza piombo | Non interessato da REACH
TAJA106M010RNJ | AVX Corporation | 478-1657-1-ND |  | C1, C11 | Cut Tape (CT) | Active | 6 | 0,30000 | € 1,80 | 0 | 35 Settimane | CAP TANT 10UF 20% 10V 1206 | A norma ROHS3 | Senza piombo | Non interessato da REACH
T491A226M010AT | KEMET | 399-3692-1-ND |  | C2 | Cut Tape (CT) | Active | 3 | 0,66000 | € 1,98 | 52253 | 44 Settimane | CAP TANT 22UF 20% 10V 1206 | A norma ROHS3 | Senza piombo | Non interessato da REACH
STM32F401RBT6TR | STMicroelectronics | 497-18782-1-ND |  |  | Cut Tape (CT) | Active | 3 | 4,60000 | € 13,80 | U3 | 26 Settimane | IC MCU 32BIT 128KB FLASH 64LQFP | A norma ROHS3 | Senza piombo | Non interessato da REACH

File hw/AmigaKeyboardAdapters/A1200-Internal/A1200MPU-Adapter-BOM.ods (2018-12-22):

Reference | Value | Footprint | Datasheet
C1 | 10uF | SMD_Packages:SMD-1206_Pol
C2 | 10uF | SMD_Packages:SMD-1206_Pol
C3 | 100nF | Capacitors_SMD:C_1206_HandSoldering
C4 | 100nF | Capacitors_SMD:C_1206_HandSoldering
D1 | Led_Small | SMD_Packages:SMD-1206_Pol
P1 | CONN_02X03 | Pin_Headers:Pin_Header_Straight_2x03
R1 | 330 | Resistors_SMD:R_1206_HandSoldering
U1 | A1200U13_REV_PLCC44 | Sockets:PLCC44

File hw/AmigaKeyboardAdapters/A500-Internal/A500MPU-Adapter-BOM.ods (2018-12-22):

Reference | Value | Footprint | Datasheet
D1 | LED GREEN | SMD_Packages:SMD-1206_Pol
D2 | DISK YELLOW | SMD_Packages:SMD-1206_Pol
D3 | READY RED | SMD_Packages:SMD-1206_Pol
P1 | CONN_01X08 | Pin_Headers:Pin_Header_Straight_1x08
P2 | CONN_01X08 | Socket_Strips:Socket_Strip_Straight_1x08
P3 | CONN_02X03 | Pin_Headers:Pin_Header_Straight_2x03
P4 | CONN_01X02 | Pin_Headers:Pin_Header_Straight_1x02
P5 | CONN_01X02 | Pin_Headers:Pin_Header_Straight_1x02
R1 | 330 | Resistors_SMD:R_1206_HandSoldering
R2 | 330 | Resistors_SMD:R_1206_HandSoldering
R3 | 330 | Resistors_SMD:R_1206_HandSoldering
R4 | 330 | Resistors_SMD:R_1206_HandSoldering
R5 | 330 | Resistors_SMD:R_1206_HandSoldering

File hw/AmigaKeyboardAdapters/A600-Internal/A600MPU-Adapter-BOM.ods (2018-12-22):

Reference | Value | Footprint | Datasheet
C1 | 10uF | Capacitors_SMD:c_elec_3x5.3
C2 | 100nF | Capacitors_SMD:C_0603_HandSoldering
C3 | 10uF | Capacitors_SMD:c_elec_3x5.3
C4 | 100nF | Capacitors_SMD:C_0603_HandSoldering
D1 | Led_Small | SMD_Packages:SMD-1206_Pol
P1 | CONN_02X03 | Pin_Headers:Pin_Header_Straight_2x03
P2 | CONN_01X03 | Pin_Headers:Pin_Header_Straight_1x03
R1 | 330 | Resistors_SMD:R_0603_HandSoldering
U1 | 6571R4_PLCC44_MPUKEY_REV | Sockets:PLCC44

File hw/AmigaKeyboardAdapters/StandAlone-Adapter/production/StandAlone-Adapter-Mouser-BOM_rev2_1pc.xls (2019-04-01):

CARRELLO
Questa non è una fattura
01-apr-19 02:14:24
 | N. Mouser | N. produttore | Produttore | N. cliente | Descrizione | RoHS: | Ciclo di vita | Q.tà ordine | Prezzo (EUR) | Prezzo esteso: (EUR)
1 | 647-UZS0G470MCL1GB | UZS0G470MCL1GB | Nichicon |  | Condensatori elettrolitici in alluminio - SMD 4volts 47uF 85c 4X4.5 | A norma RoHS |  | 1 | 0,428 € | 0,43 €
2 | 710-865250140001 | 865250140001 | Wurth Electronics |  | Condensatori elettrolitici in alluminio - SMD WCAP-ASNP 6.3V 10uF 20% ESR=16803mOhms | A norma RoHS |  | 1 | 0,25 € | 0,25 €
3 | 710-865080140001 | 865080140001 | Wurth Electronics |  | Condensatori elettrolitici in alluminio - SMD WCAP-ASLI 6.3V 22uF 20% ESR=2200mOhms | A norma RoHS |  | 1 | 0,15 € | 0,15 €
4 | 581-12061C104K4Z4A | 12061C104K4Z4A | AVX |  | Condensatori in ceramica multistrato MLCC - SMD/SMT 100V .1uF X7R 1206 10%TOL AEC-Q200 | A norma RoHS | Nuovo prodotto | 4 | 0,41 € | 1,64 €
5 | 80-C1206C220JBGAUTO | C1206C220JBGACAUTO | KEMET |  | Condensatori in ceramica multistrato MLCC - SMD/SMT 630V 22pF C0G 1206 5% AEC-Q200 | A norma RoHS | Nuovo prodotto | 4 | 0,899 € | 3,60 €
6 | 511-STM32F401RCT6 | STM32F401RCT6 | STMicroelectronics |  | Microcontrollori ARM - MCU Cost effective DSP FPU ARM CortexM4 MCU | A norma RoHS |  | 1 | 5,37 € | 5,37 €
7 | 926-LM1117IMPX33NOPB | LM1117IMPX-3.3/NOPB | Texas Instruments |  | Regolatori di tensione LDO 800MA LDO LINEAR REG | A norma RoHS |  | 1 | 0,961 € | 0,96 €
8 | 512-BSS138 | BSS138 | ON Semiconductor |  | MOSFET SOT-23 N-CH LOGIC | A norma RoHS |  | 3 | 0,262 € | 0,79 €
9 | 710-615004143821 | 615004143821 | Wurth Electronics |  | Connettori modulari/Connettori Ethernet WR-COM Modular Jack 4P4C Horztl Female | A norma RoHS |  | 1 | 1,11 € | 1,11 €
10 | 710-150120AS75000 | 150120AS75000 | Wurth Electronics |  | LED standard - SMD WL-SMCW SMDMono TpVw Waterclr 1206 Amber | A norma RoHS |  | 1 | 0,19 € | 0,19 €
11 | 645-599-0281-007F | 599-0281-007F | Dialight |  | LED standard - SMD SMD 1206 GREEN | A norma RoHS | Nuovo prodotto | 1 | 0,445 € | 0,45 €
12 | 645-599-0210-007F | 599-0210-007F | Dialight |  | LED standard - SMD SMD 1206 RED | A norma RoHS | Nuovo prodotto | 2 | 0,349 € | 0,70 €
13 | 71-CRCW1206330RJNEAC | CRCW1206330RJNEAC | Vishay |  | Resistori a pellicola spessa - SMD 1/4Watt 330ohms 5% Commercial Use | Conforme RoHS per esenzione | Nuovo prodotto | 2 | 0,157 € | 0,31 €
14 | 71-CRCW1206220RJNEAC | CRCW1206220RJNEAC | Vishay |  | Resistori a pellicola spessa - SMD 1/4Watt 220ohms 5% Commercial Use | Conforme RoHS per esenzione | Nuovo prodotto | 1 | 0,166 € | 0,17 €
15 | 71-CRCW120610K0JNEAC | CRCW120610K0JNEAC | Vishay |  | Resistori a pellicola spessa - SMD 1/4Watt 10Kohms 5% Commercial Use | Conforme RoHS per esenzione | Nuovo prodotto | 9 | 0,166 € | 1,49 €
16 | 71-CRCW12061K00JNEAC | CRCW12061K00JNEAC | Vishay |  | Resistori a pellicola spessa - SMD 1/4Watt 1Kohms 5% Commercial Use | Conforme RoHS per esenzione | Nuovo prodotto | 1 | 0,087 € | 0,09 €
17 | 538-67643-3910 | 67643-3910 | Molex |  | Connettori USB USB REC 4P RA SHLD TYPE A AUFL | A norma RoHS |  | 1 | 1,34 € | 1,34 €
18 | 449-LFXTAL029488BULK | LFXTAL029488Bulk | IQD Frequency Products |  | Cristalli 8MHz 22pF -20C 70C | A norma RoHS |  | 1 | 0,594 € | 0,59 €
19 | 200-TST11301SD | TST-113-01-S-D | Samtec |  | Terminali e capicorda .100" Shrouded Terminal Strip, Cable Mate | A norma RoHS | Nuovo a Mouser | 1 | 3,66 € | 3,66 €
20 | 538-22-05-2151 | 22-05-2151 | Molex |  | Terminali e capicorda 15 CKT R/A HEADER | A norma RoHS |  | 1 | 1,12 € | 1,12 €
21 | 855-M20-9771546 | M20-9771546 | Harwin |  | Terminali e capicorda 15 SIL VERTICAL PIN HEADER TIN | A norma RoHS |  | 1 | 0,419 € | 0,42 €
22 | 652-SDR1005-101KL | SDR1005-101KL | Bourns |  | Induttori fissi 100uH 10% SMD 1005 | A norma RoHS |  | 2 | 0,594 € | 1,19 €
Inviando l'ordine si accettano queste termini e condizioni. (https://www.mouser.it/saleterms) |  |  |  |  |  |  |  |  | Totale articoli acquistati: | 26,02 €
I prezzi riflettono quelli validi alla data e all'ora mostrate. |  |  |  |  |  |  |  |  | Spese di spedizione: | 20,00 €

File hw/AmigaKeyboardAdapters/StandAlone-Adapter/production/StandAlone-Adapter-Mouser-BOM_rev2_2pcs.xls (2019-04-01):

CARRELLO
Questa non è una fattura
01-apr-19 02:17:07
 | N. Mouser | N. produttore | Produttore | N. cliente | Descrizione | RoHS: | Ciclo di vita | Q.tà ordine | Prezzo (EUR) | Prezzo esteso: (EUR)
1 | 647-UZS0G470MCL1GB | UZS0G470MCL1GB | Nichicon |  | Condensatori elettrolitici in alluminio - SMD 4volts 47uF 85c 4X4.5 | A norma RoHS |  | 2 | 0,428 € | 0,86 €
2 | 710-865250140001 | 865250140001 | Wurth Electronics |  | Condensatori elettrolitici in alluminio - SMD WCAP-ASNP 6.3V 10uF 20% ESR=16803mOhms | A norma RoHS |  | 2 | 0,25 € | 0,50 €
3 | 710-865080140001 | 865080140001 | Wurth Electronics |  | Condensatori elettrolitici in alluminio - SMD WCAP-ASLI 6.3V 22uF 20% ESR=2200mOhms | A norma RoHS |  | 2 | 0,15 € | 0,30 €
4 | 581-12061C104K4Z4A | 12061C104K4Z4A | AVX |  | Condensatori in ceramica multistrato MLCC - SMD/SMT 100V .1uF X7R 1206 10%TOL AEC-Q200 | A norma RoHS | Nuovo prodotto | 8 | 0,41 € | 3,28 €
5 | 80-C1206C220JBGAUTO | C1206C220JBGACAUTO | KEMET |  | Condensatori in ceramica multistrato MLCC - SMD/SMT 630V 22pF C0G 1206 5% AEC-Q200 | A norma RoHS | Nuovo prodotto | 8 | 0,899 € | 7,19 €
6 | 511-STM32F401RCT6 | STM32F401RCT6 | STMicroelectronics |  | Microcontrollori ARM - MCU Cost effective DSP FPU ARM CortexM4 MCU | A norma RoHS |  | 2 | 5,37 € | 10,74 €
7 | 926-LM1117IMPX33NOPB | LM1117IMPX-3.3/NOPB | Texas Instruments |  | Regolatori di tensione LDO 800MA LDO LINEAR REG | A norma RoHS |  | 2 | 0,961 € | 1,92 €
8 | 512-BSS138 | BSS138 | ON Semiconductor |  | MOSFET SOT-23 N-CH LOGIC | A norma RoHS |  | 6 | 0,262 € | 1,57 €
9 | 710-615004143821 | 615004143821 | Wurth Electronics |  | Connettori modulari/Connettori Ethernet WR-COM Modular Jack 4P4C Horztl Female | A norma RoHS |  | 2 | 1,11 € | 2,22 €
10 | 710-150120AS75000 | 150120AS75000 | Wurth Electronics |  | LED standard - SMD WL-SMCW SMDMono TpVw Waterclr 1206 Amber | A norma RoHS |  | 2 | 0,19 € | 0,38 €
11 | 645-599-0281-007F | 599-0281-007F | Dialight |  | LED standard - SMD SMD 1206 GREEN | A norma RoHS | Nuovo prodotto | 2 | 0,445 € | 0,89 €
12 | 645-599-0210-007F | 599-0210-007F | Dialight |  | LED standard - SMD SMD 1206 RED | A norma RoHS | Nuovo prodotto | 4 | 0,349 € | 1,40 €
13 | 71-CRCW1206330RJNEAC | CRCW1206330RJNEAC | Vishay |  | Resistori a pellicola spessa - SMD 1/4Watt 330ohms 5% Commercial Use | Conforme RoHS per esenzione | Nuovo prodotto | 4 | 0,157 € | 0,63 €
14 | 71-CRCW1206220RJNEAC | CRCW1206220RJNEAC | Vishay |  | Resistori a pellicola spessa - SMD 1/4Watt 220ohms 5% Commercial Use | Conforme RoHS per esenzione | Nuovo prodotto | 2 | 0,166 € | 0,33 €
15 | 71-CRCW120610K0JNEAC | CRCW120610K0JNEAC | Vishay |  | Resistori a pellicola spessa - SMD 1/4Watt 10Kohms 5% Commercial Use | Conforme RoHS per esenzione | Nuovo prodotto | 18 | 0,079 € | 1,42 €
16 | 71-CRCW12061K00JNEAC | CRCW12061K00JNEAC | Vishay |  | Resistori a pellicola spessa - SMD 1/4Watt 1Kohms 5% Commercial Use | Conforme RoHS per esenzione | Nuovo prodotto | 2 | 0,087 € | 0,17 €
17 | 538-67643-3910 | 67643-3910 | Molex |  | Connettori USB USB REC 4P RA SHLD TYPE A AUFL | A norma RoHS |  | 2 | 1,34 € | 2,68 €
18 | 449-LFXTAL029488BULK | LFXTAL029488Bulk | IQD Frequency Products |  | Cristalli 8MHz 22pF -20C 70C | A norma RoHS |  | 2 | 0,594 € | 1,19 €
19 | 200-TST11301SD | TST-113-01-S-D | Samtec |  | Terminali e capicorda .100" Shrouded Terminal Strip, Cable Mate | A norma RoHS | Nuovo a Mouser | 2 | 3,66 € | 7,32 €
20 | 538-22-05-2151 | 22-05-2151 | Molex |  | Terminali e capicorda 15 CKT R/A HEADER | A norma RoHS |  | 2 | 1,12 € | 2,24 €
21 | 855-M20-9771546 | M20-9771546 | Harwin |  | Terminali e capicorda 15 SIL VERTICAL PIN HEADER TIN | A norma RoHS |  | 2 | 0,419 € | 0,84 €
22 | 652-SDR1005-101KL | SDR1005-101KL | Bourns |  | Induttori fissi 100uH 10% SMD 1005 | A norma RoHS |  | 4 | 0,594 € | 2,38 €
Inviando l'ordine si accettano queste termini e condizioni. (https://www.mouser.it/saleterms) |  |  |  |  |  |  |  |  | Totale articoli acquistati: | 50,45 €
I prezzi riflettono quelli validi alla data e all'ora mostrate. |  |  |  |  |  |  |  |  | Spese di spedizione: | 0,00 €

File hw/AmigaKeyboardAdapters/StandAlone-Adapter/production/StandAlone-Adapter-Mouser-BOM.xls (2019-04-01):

CARRELLO
Questa non è una fattura
01-apr-19 02:12:00
 | N. Mouser | N. produttore | Produttore | N. cliente | Descrizione | RoHS: | Ciclo di vita | Q.tà ordine | Prezzo (EUR) | Prezzo esteso: (EUR)
1 | 647-UZS0G470MCL1GB | UZS0G470MCL1GB | Nichicon |  | Condensatori elettrolitici in alluminio - SMD 4volts 47uF 85c 4X4.5 | A norma RoHS |  | 10 | 0,293 € | 2,93 €
2 | 710-865250140001 | 865250140001 | Wurth Electronics |  | Condensatori elettrolitici in alluminio - SMD WCAP-ASNP 6.3V 10uF 20% ESR=16803mOhms | A norma RoHS |  | 10 | 0,245 € | 2,45 €
3 | 710-865080140001 | 865080140001 | Wurth Electronics |  | Condensatori elettrolitici in alluminio - SMD WCAP-ASLI 6.3V 22uF 20% ESR=2200mOhms | A norma RoHS |  | 10 | 0,148 € | 1,48 €
4 | 581-12061C104K4Z4A | 12061C104K4Z4A | AVX |  | Condensatori in ceramica multistrato MLCC - SMD/SMT 100V .1uF X7R 1206 10%TOL AEC-Q200 | A norma RoHS | Nuovo prodotto | 40 | 0,286 € | 11,44 €
5 | 80-C1206C220JBGAUTO | C1206C220JBGACAUTO | KEMET |  | Condensatori in ceramica multistrato MLCC - SMD/SMT 630V 22pF C0G 1206 5% AEC-Q200 | A norma RoHS | Nuovo prodotto | 40 | 0,685 € | 27,40 €
6 | 511-STM32F401RCT6 | STM32F401RCT6 | STMicroelectronics |  | Microcontrollori ARM - MCU Cost effective DSP FPU ARM CortexM4 MCU | A norma RoHS |  | 10 | 4,57 € | 45,70 €
7 | 926-LM1117IMPX33NOPB | LM1117IMPX-3.3/NOPB | Texas Instruments |  | Regolatori di tensione LDO 800MA LDO LINEAR REG | A norma RoHS |  | 10 | 0,821 € | 8,21 €
8 | 512-BSS138 | BSS138 | ON Semiconductor |  | MOSFET SOT-23 N-CH LOGIC | A norma RoHS |  | 30 | 0,243 € | 7,29 €
9 | 710-615004143821 | 615004143821 | Wurth Electronics |  | Connettori modulari/Connettori Ethernet WR-COM Modular Jack 4P4C Horztl Female | A norma RoHS |  | 10 | 1,06 € | 10,60 €
10 | 710-150120AS75000 | 150120AS75000 | Wurth Electronics |  | LED standard - SMD WL-SMCW SMDMono TpVw Waterclr 1206 Amber | A norma RoHS |  | 10 | 0,183 € | 1,83 €
11 | 645-599-0281-007F | 599-0281-007F | Dialight |  | LED standard - SMD SMD 1206 GREEN | A norma RoHS | Nuovo prodotto | 10 | 0,29 € | 2,90 €
12 | 645-599-0210-007F | 599-0210-007F | Dialight |  | LED standard - SMD SMD 1206 RED | A norma RoHS | Nuovo prodotto | 20 | 0,203 € | 4,06 €
13 | 71-CRCW1206330RJNEAC | CRCW1206330RJNEAC | Vishay |  | Resistori a pellicola spessa - SMD 1/4Watt 330ohms 5% Commercial Use | Conforme RoHS per esenzione | Nuovo prodotto | 20 | 0,078 € | 1,56 €
14 | 71-CRCW1206220RJNEAC | CRCW1206220RJNEAC | Vishay |  | Resistori a pellicola spessa - SMD 1/4Watt 220ohms 5% Commercial Use | Conforme RoHS per esenzione | Nuovo prodotto | 10 | 0,079 € | 0,79 €
15 | 71-CRCW120610K0JNEAC | CRCW120610K0JNEAC | Vishay |  | Resistori a pellicola spessa - SMD 1/4Watt 10Kohms 5% Commercial Use | Conforme RoHS per esenzione | Nuovo prodotto | 90 | 0,079 € | 7,11 €
16 | 71-CRCW12061K00JNEAC | CRCW12061K00JNEAC | Vishay |  | Resistori a pellicola spessa - SMD 1/4Watt 1Kohms 5% Commercial Use | Conforme RoHS per esenzione | Nuovo prodotto | 10 | 0,049 € | 0,49 €
17 | 538-67643-3910 | 67643-3910 | Molex |  | Connettori USB USB REC 4P RA SHLD TYPE A AUFL | A norma RoHS |  | 10 | 1,17 € | 11,70 €
18 | 449-LFXTAL029488BULK | LFXTAL029488Bulk | IQD Frequency Products |  | Cristalli 8MHz 22pF -20C 70C | A norma RoHS |  | 10 | 0,594 € | 5,94 €
19 | 200-TST11301SD | TST-113-01-S-D | Samtec |  | Terminali e capicorda .100" Shrouded Terminal Strip, Cable Mate | A norma RoHS | Nuovo a Mouser | 10 | 3,09 € | 30,90 €
20 | 538-22-05-2151 | 22-05-2151 | Molex |  | Terminali e capicorda 15 CKT R/A HEADER | A norma RoHS |  | 10 | 0,978 € | 9,78 €
21 | 855-M20-9771546 | M20-9771546 | Harwin |  | Terminali e capicorda 15 SIL VERTICAL PIN HEADER TIN | A norma RoHS |  | 10 | 0,334 € | 3,34 €
22 | 652-SDR1005-101KL | SDR1005-101KL | Bourns |  | Induttori fissi 100uH 10% SMD 1005 | A norma RoHS |  | 20 | 0,409 € | 8,18 €
Inviando l'ordine si accettano queste termini e condizioni. (https://www.mouser.it/saleterms) |  |  |  |  |  |  |  |  | Totale articoli acquistati: | 206,08 €
I prezzi riflettono quelli validi alla data e all'ora mostrate. |  |  |  |  |  |  |  |  | Spese di spedizione: | 0,00 €

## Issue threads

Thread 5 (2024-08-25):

Replacing the controller

volton-svg, 2024-08-25:
Good afternoon! Is it possible to replace 32stm401rct6 with 32stm401ret6?

reinauer, 2024-08-25:
Yes, the footprint is the same for both the STM32F401RCT6 and STM32F401RET6. Both microcontrollers come in the LQFP64 (64-pin) package, meaning they have the same physical dimensions, pin layout, and footprint. This makes them interchangeable in terms of hardware design, provided that the memory difference is accounted for in the application.

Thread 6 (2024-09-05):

Not working

volton-svg, 2024-09-05:
Hi all!
I’ll describe it briefly... stm32f401re6 was installed, flashed with st-link, first flashed - stalkb-bootloader.hex then stm32f401-usb-keyboard-amiga.hex. everything went through the check without errors. jumper boot 0 is set to ground, jumper j9 is in the closed position. When you turn it on for the first time and without a USB keyboard connected, the activity LED starts flashing after a while when the keyboard is connected, it is constantly on, which seems to be everything is ok. When connected to the a2000, the keyboard does not react at all... soldering has been checked several times! Where to dig next? I think the length of the wire itself to the controller from the Amiga is somewhere around 50-60cm... can it be shortened?

volton-svg, 2024-09-13:
It was possible to launch this controller with a different keyboard. But again a problem arose that the enter keys were misplaced, that is, the numpad enter worked as the main one... the firmware was changed, which I attach -
[stm32f401-usb-keyboard-amiga.zip](https://github.com/user-attachments/files/16988610/stm32f401-usb-keyboard-amiga.zip)

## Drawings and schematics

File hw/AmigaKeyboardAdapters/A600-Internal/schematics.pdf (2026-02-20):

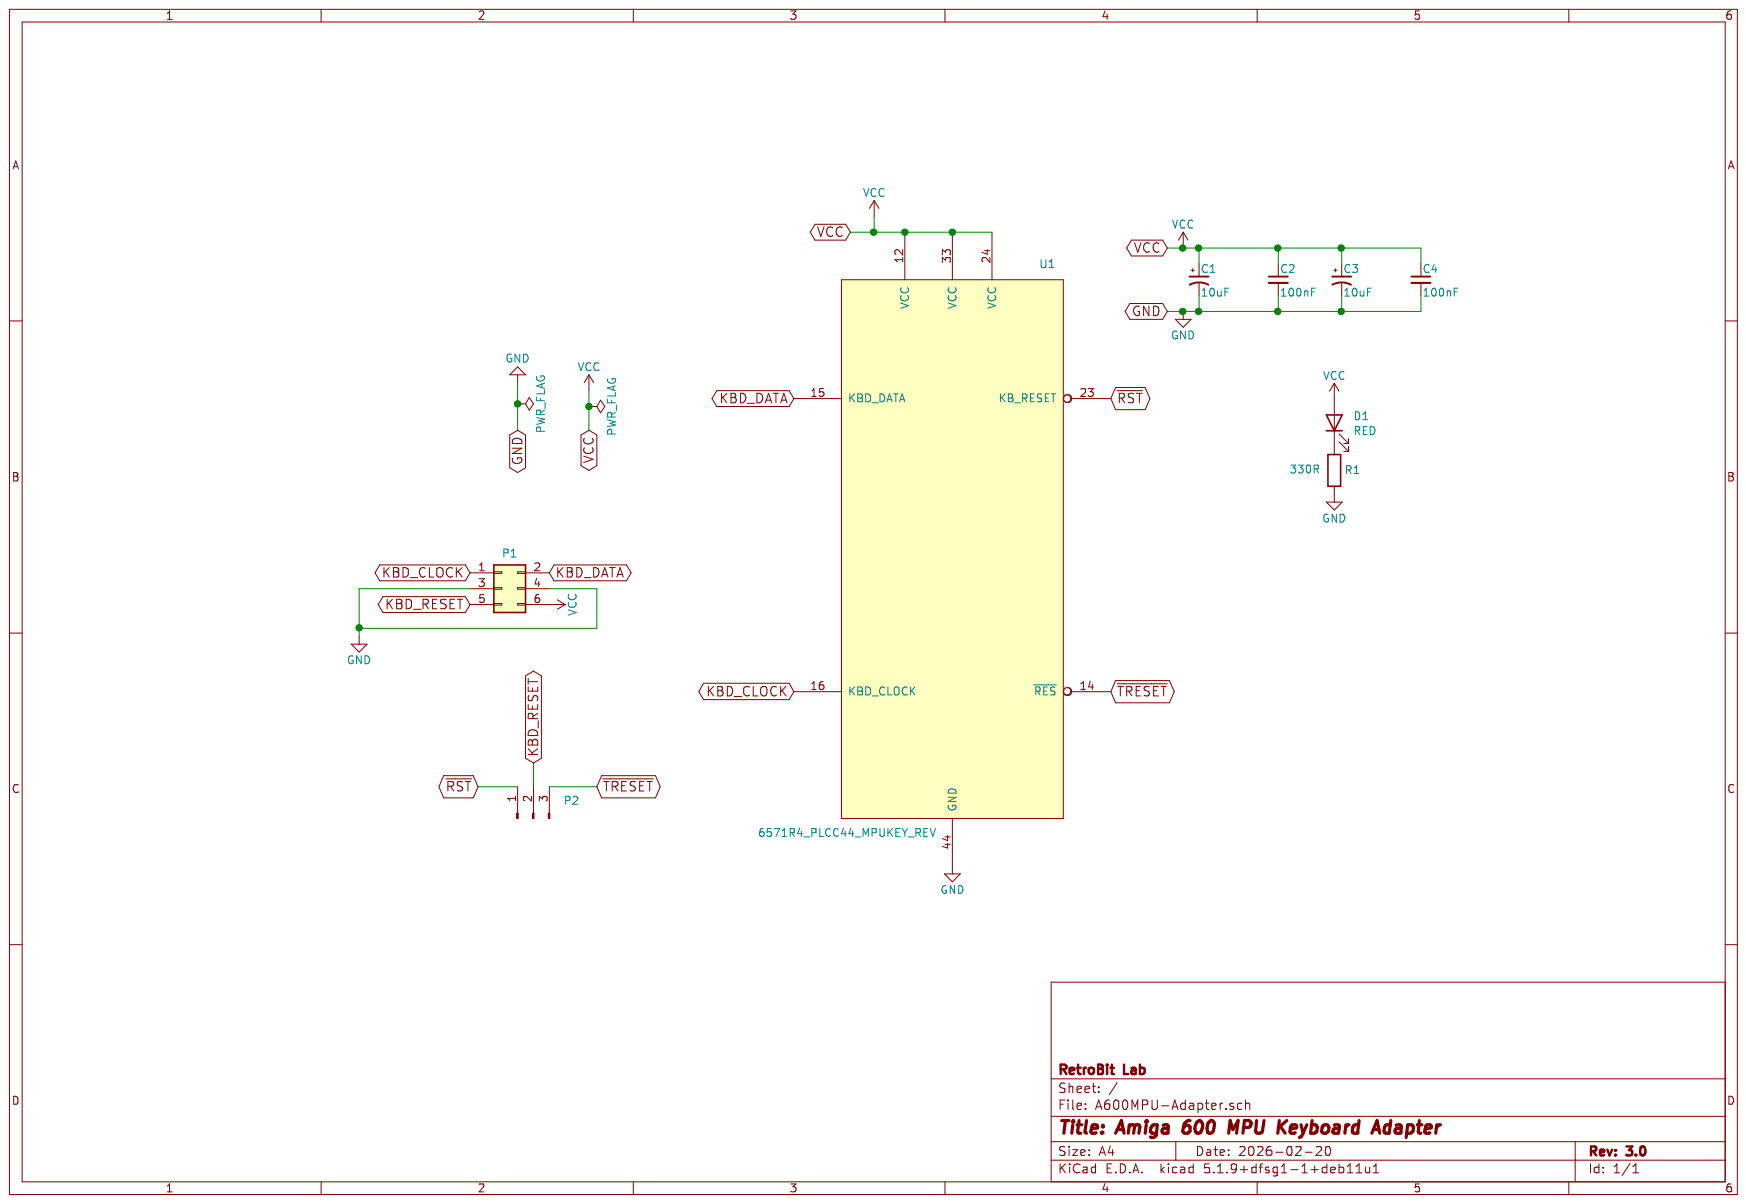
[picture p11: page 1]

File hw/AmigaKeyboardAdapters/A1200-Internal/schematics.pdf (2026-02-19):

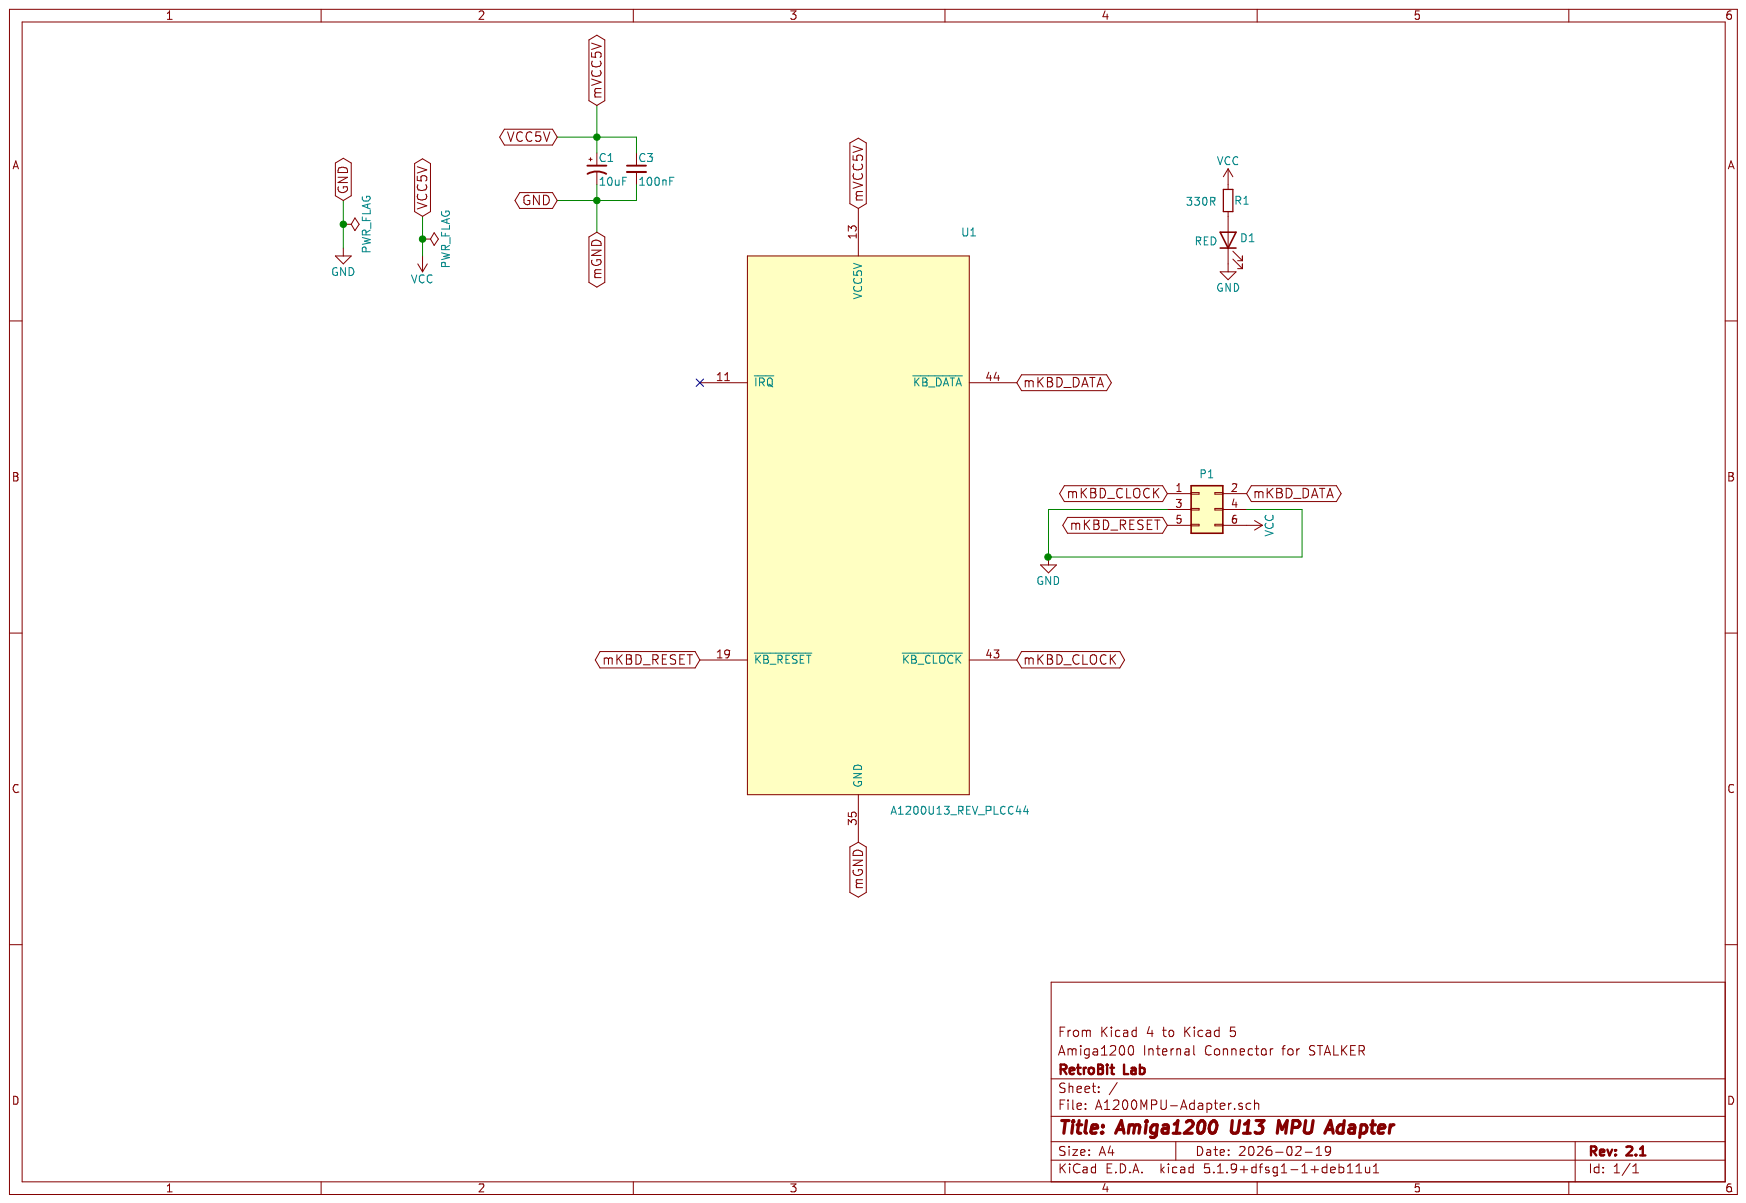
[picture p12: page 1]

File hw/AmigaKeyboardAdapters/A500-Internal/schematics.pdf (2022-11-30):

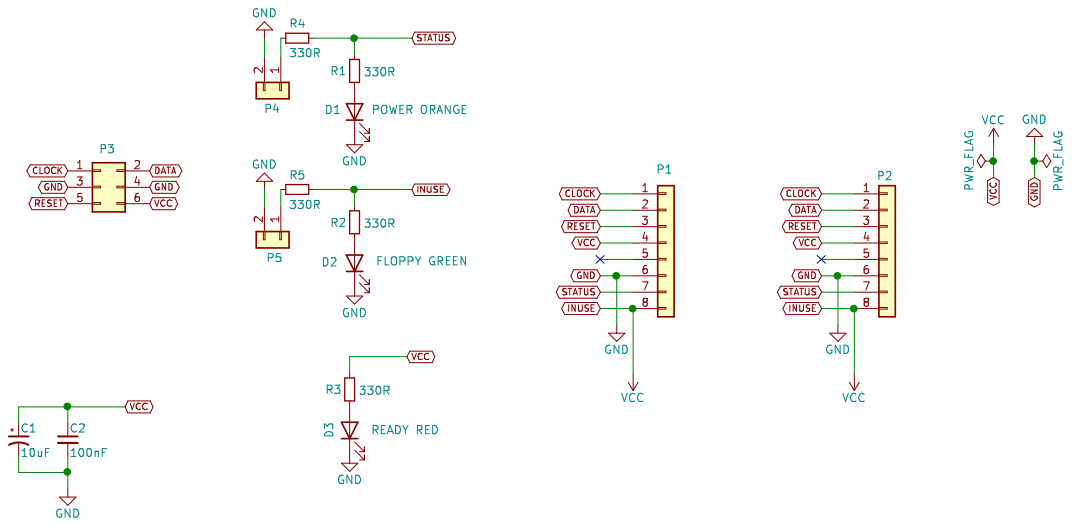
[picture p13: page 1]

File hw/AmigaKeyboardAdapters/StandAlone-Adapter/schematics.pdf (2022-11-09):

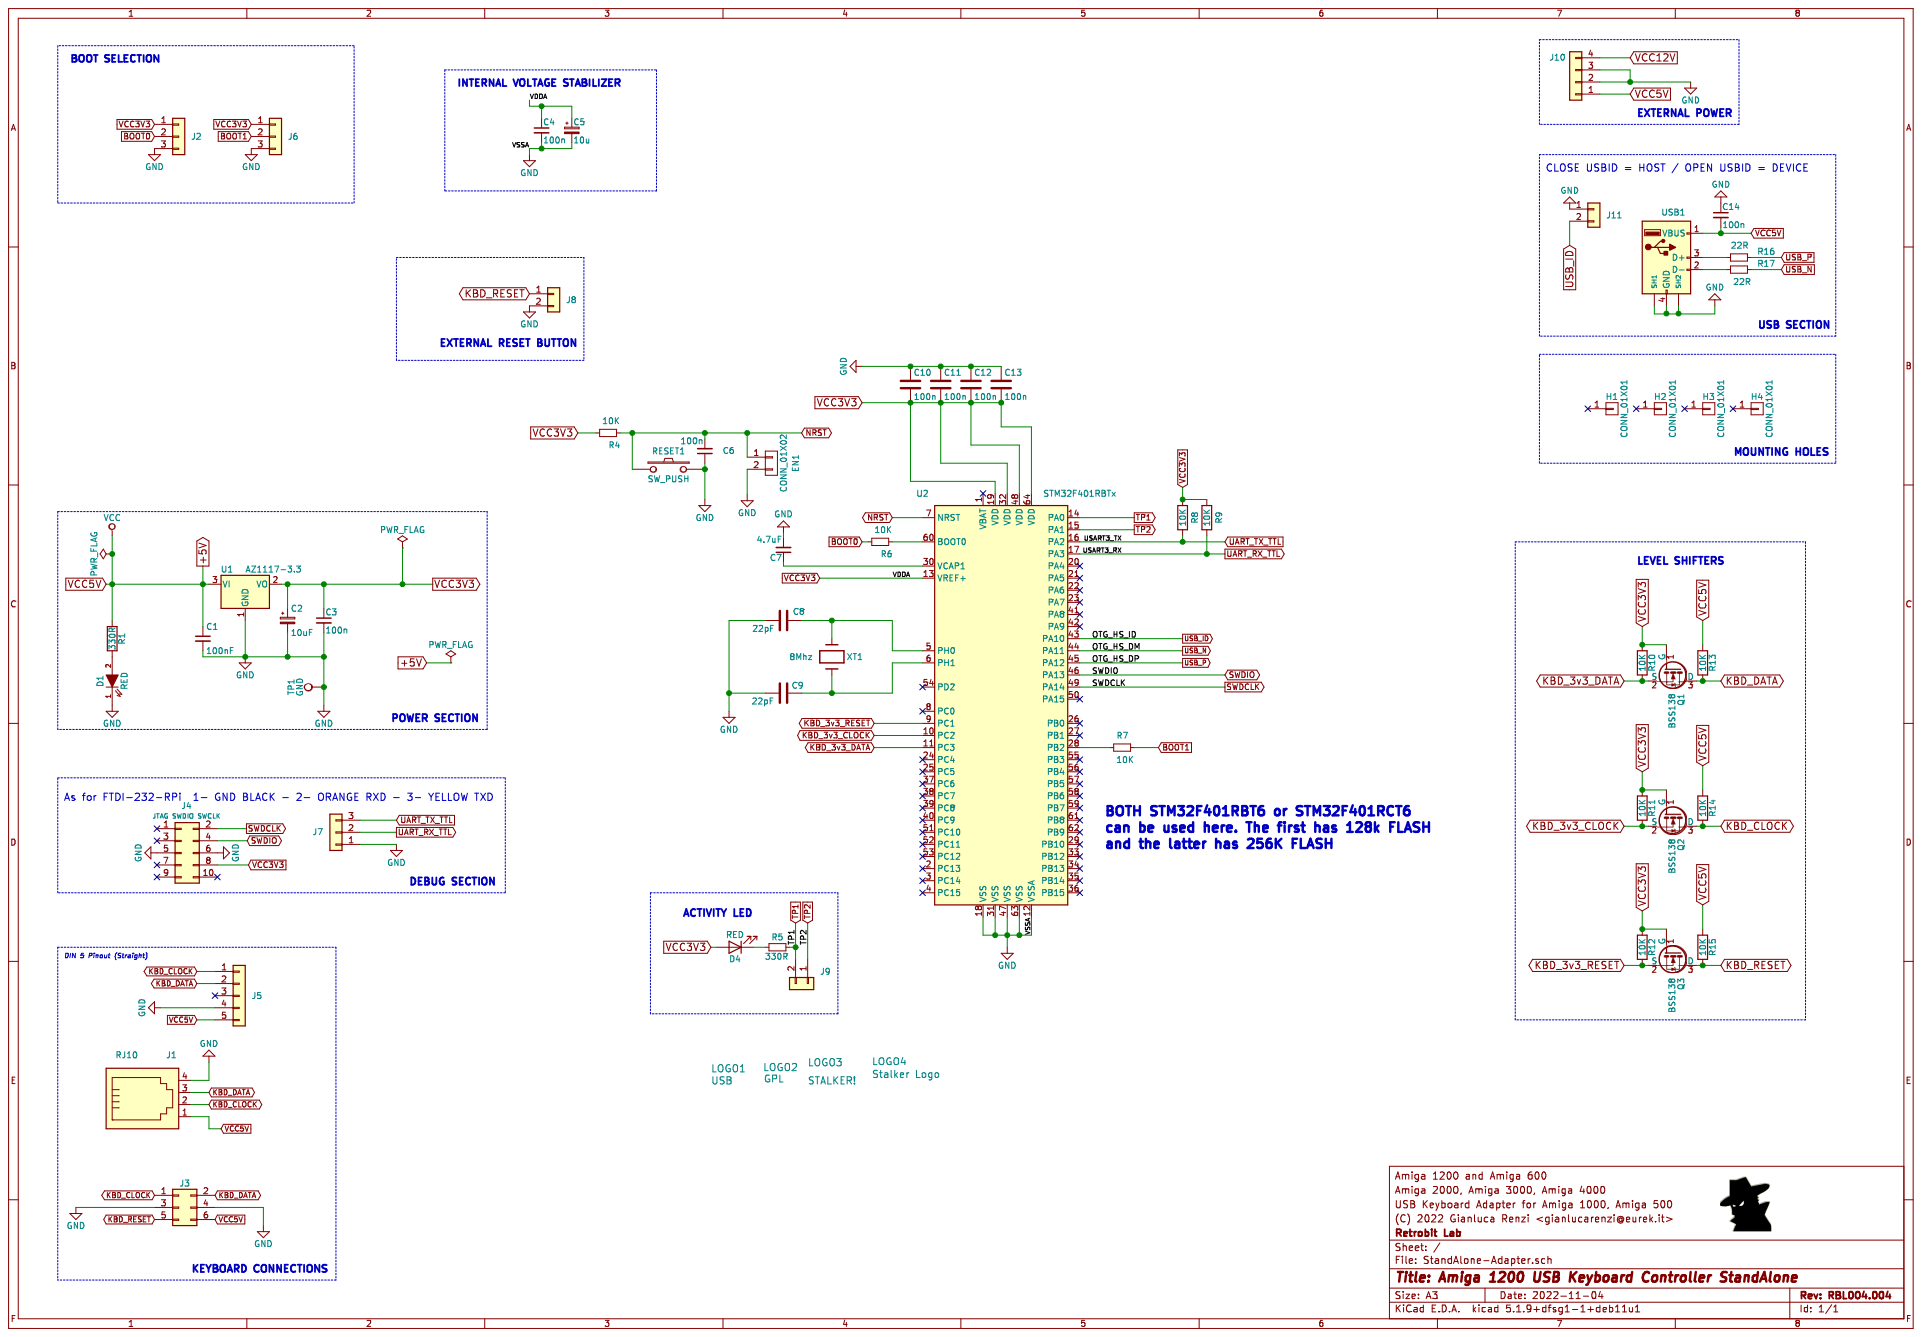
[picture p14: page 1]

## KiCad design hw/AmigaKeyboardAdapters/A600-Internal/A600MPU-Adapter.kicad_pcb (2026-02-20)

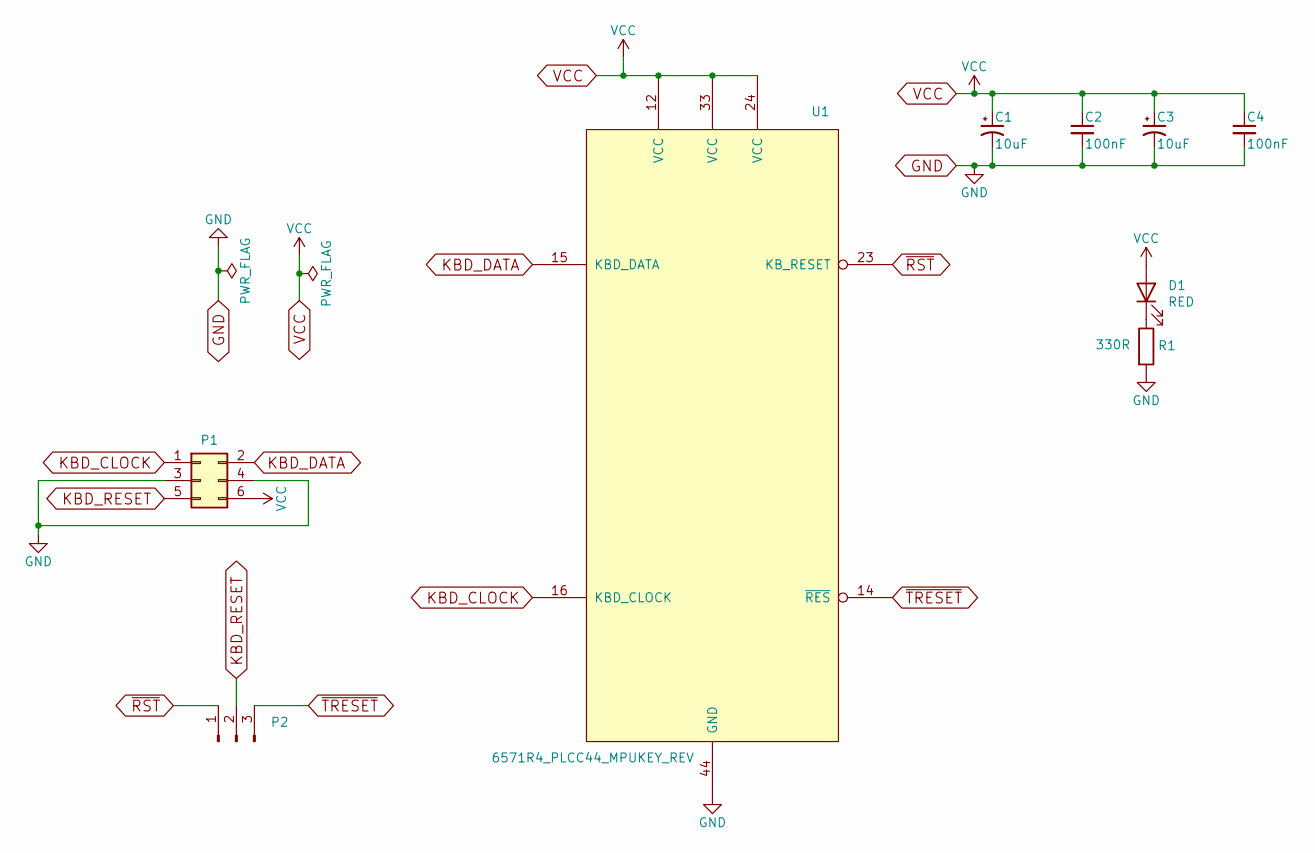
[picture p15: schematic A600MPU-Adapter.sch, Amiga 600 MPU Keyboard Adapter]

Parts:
C1, C3: 10uF; CP_EIA-3216-12_Kemet-S_Pad1.58x1.35mm_HandSolder; LCSC C108529
C2, C4: 100nF; C_1206_3216Metric_Pad1.33x1.80mm_HandSolder; LCSC C24497
D1: RED; LED_1206_3216Metric_Pad1.42x1.75mm_HandSolder; LCSC C93133
P1: Conn_02x03_Odd_Even; IDC-Header_2x03_P2.54mm_Vertical
P2: Conn_01x03_Male; PinHeader_1x03_P2.54mm_Vertical
R1: 330R; R_1206_3216Metric_Pad1.30x1.75mm_HandSolder; LCSC C245520
U1: 6571R4_PLCC44_MPUKEY_REV; PLCC-44_THT-Socket_3D

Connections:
GND: C1.2, C2.2, C3.2, C4.2, P1.3, P1.4, R1.2, U1.44 (GND)
KBD_CLOCK: P1.1, U1.16 (KBD_CLOCK)
KBD_DATA: P1.2, U1.15 (KBD_DATA)
KBD_RESET: P1.5, P2.2
unnamed: D1.1 (K), R1.1
VCC: C1.1, C2.1, C3.1, C4.1, D1.2 (A), P1.6, U1.12 (VCC), U1.24 (VCC), U1.33 (VCC)
~RST: P2.1, U1.23 (KB_RESET)
~TRESET: P2.3, U1.14 (~RES)

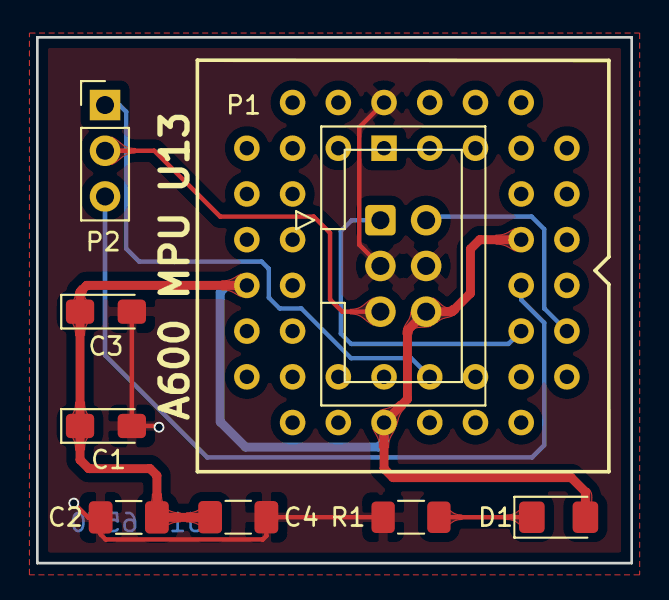
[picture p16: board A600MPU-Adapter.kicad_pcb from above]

Board: 2 copper layers, 33.0 x 29.2 mm, 9 parts (1 on the bottom side), 8 nets.

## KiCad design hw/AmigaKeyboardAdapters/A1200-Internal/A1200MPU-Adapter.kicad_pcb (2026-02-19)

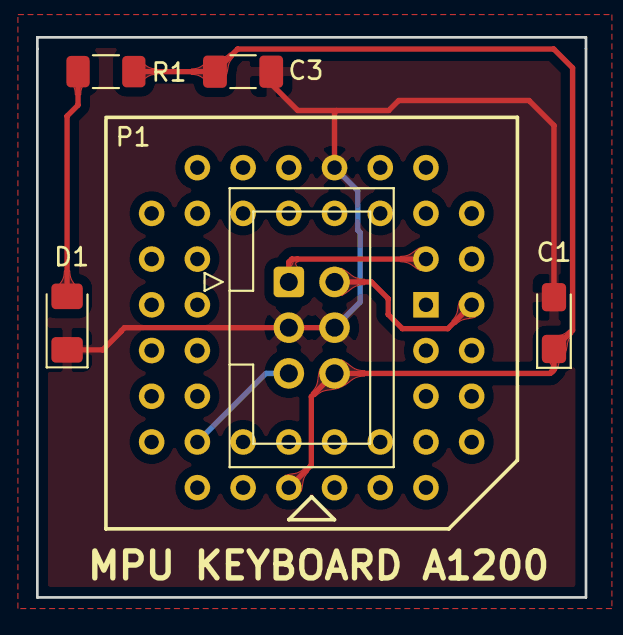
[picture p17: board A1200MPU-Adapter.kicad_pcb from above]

Board: 2 copper layers, 30.5 x 31.1 mm, 6 parts (1 on the bottom side), 6 nets.

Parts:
C1: 10uF; CP_EIA-3216-12_Kemet-S_Pad1.58x1.35mm_HandSolder
C3: 100nF; C_1206_3216Metric_Pad1.33x1.80mm_HandSolder
D1: RED; LED_1206_3216Metric_Pad1.42x1.75mm_HandSolder
P1: Conn_02x03_Odd_Even; IDC-Header_2x03_P2.54mm_Vertical
R1: 330R; R_1206_3216Metric_Pad1.30x1.75mm_HandSolder
U1: A1200U13_REV_PLCC44; PLCC-44_THT-Socket_3D

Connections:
GND: C1.2, C3.2, D1.1, P1.3, P1.4, U1.35
unnamed: D1.2, R1.1
VCC5V: C1.1, C3.1, P1.6, R1.2, U1.13
mKBD_CLOCK: P1.1, U1.43
mKBD_DATA: P1.2, U1.44
mKBD_RESET: P1.5, U1.19

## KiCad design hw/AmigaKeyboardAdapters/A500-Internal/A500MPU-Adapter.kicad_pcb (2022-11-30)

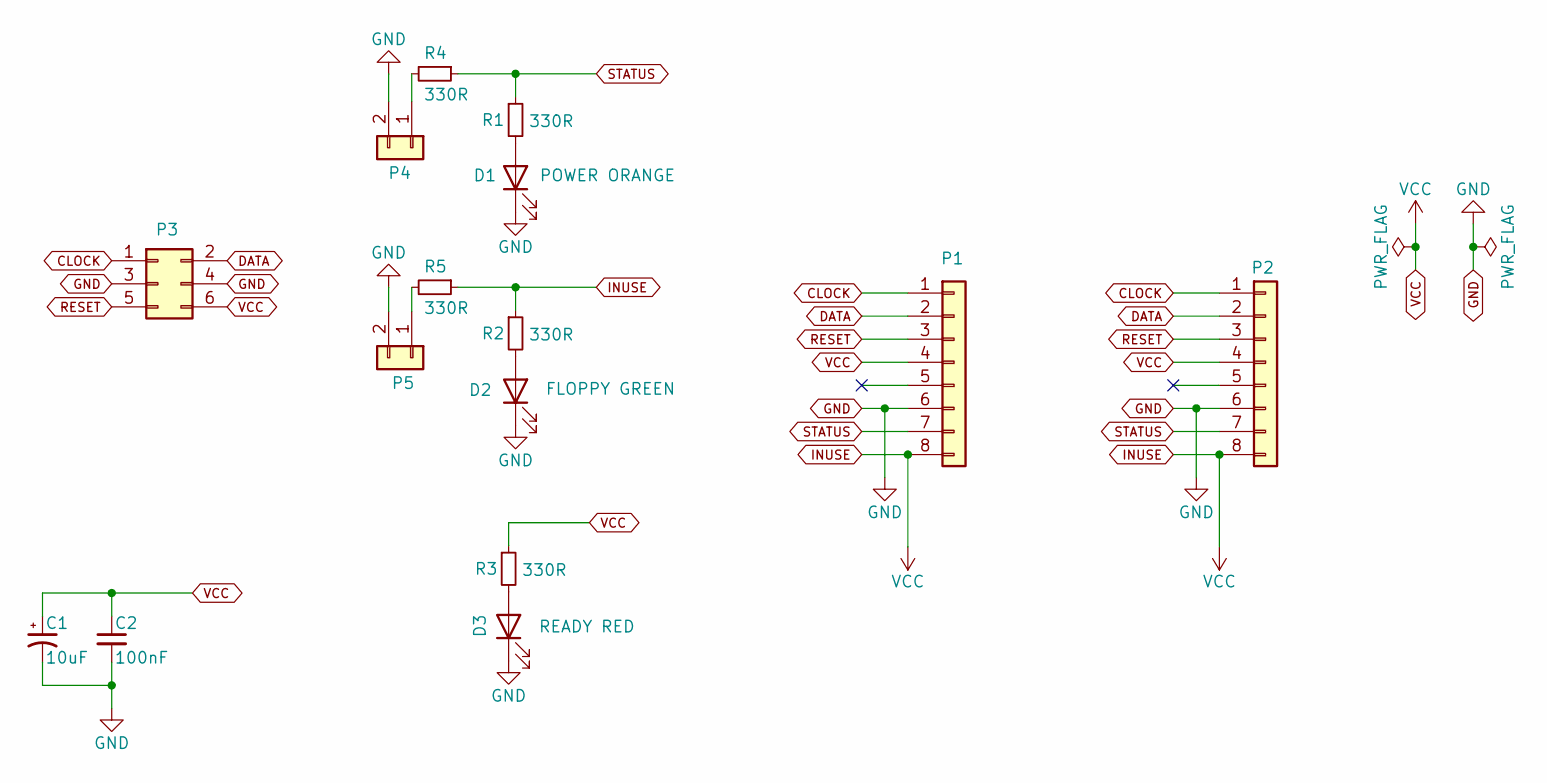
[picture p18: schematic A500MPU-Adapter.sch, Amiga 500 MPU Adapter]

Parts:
C1: 10uF; CP_EIA-3216-12_Kemet-S_Pad1.58x1.35mm_HandSolder; LCSC C108529
C2: 100nF; C_1206_3216Metric_Pad1.33x1.80mm_HandSolder; LCSC C24497
D1: POWER ORANGE; LED_1206_3216Metric_Pad1.42x1.75mm_HandSolder; LCSC C183851
D2: FLOPPY GREEN; LED_1206_3216Metric_Pad1.42x1.75mm_HandSolder; LCSC C2980185
D3: READY RED; LED_1206_3216Metric_Pad1.42x1.75mm_HandSolder; LCSC C93133
P1: Conn_01x08; PinHeader_1x08_P2.54mm_Vertical
P2: Conn_01x08; PinSocket_1x08_P2.54mm_Vertical
P3: Conn_02x03; IDC-Header_2x03_P2.54mm_Vertical
P4, P5: Conn_01x02; PinHeader_1x02_P2.54mm_Vertical
R1, R2, R3, R4, R5: 330R; R_1206_3216Metric_Pad1.30x1.75mm_HandSolder; LCSC C245520

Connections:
CLOCK: P1.1, P2.1, P3.1
DATA: P1.2, P2.2, P3.2
GND: C1.2, C2.2, D1.1 (K), D2.1 (K), D3.1 (K), P1.6, P2.6, P3.3, P3.4, P4.2, P5.2
INUSE: C1.1, C2.1, P1.4, P1.8, P2.4, P2.8, P3.6, R2.1, R3.1, R5.1
unnamed: D1.2 (A), R1.2
unnamed: D2.2 (A), R2.2
unnamed: D3.2 (A), R3.2
unnamed: P4.1, R4.2
unnamed: P5.1, R5.2
RESET: P1.3, P2.3, P3.5
STATUS: P1.7, P2.7, R1.1, R4.1

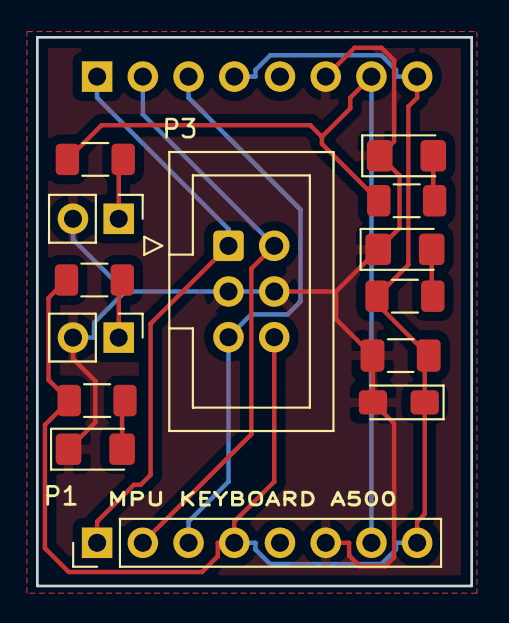
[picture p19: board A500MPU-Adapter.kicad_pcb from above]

Board: 2 copper layers, 24.1 x 30.5 mm, 15 parts (1 on the bottom side), 11 nets.

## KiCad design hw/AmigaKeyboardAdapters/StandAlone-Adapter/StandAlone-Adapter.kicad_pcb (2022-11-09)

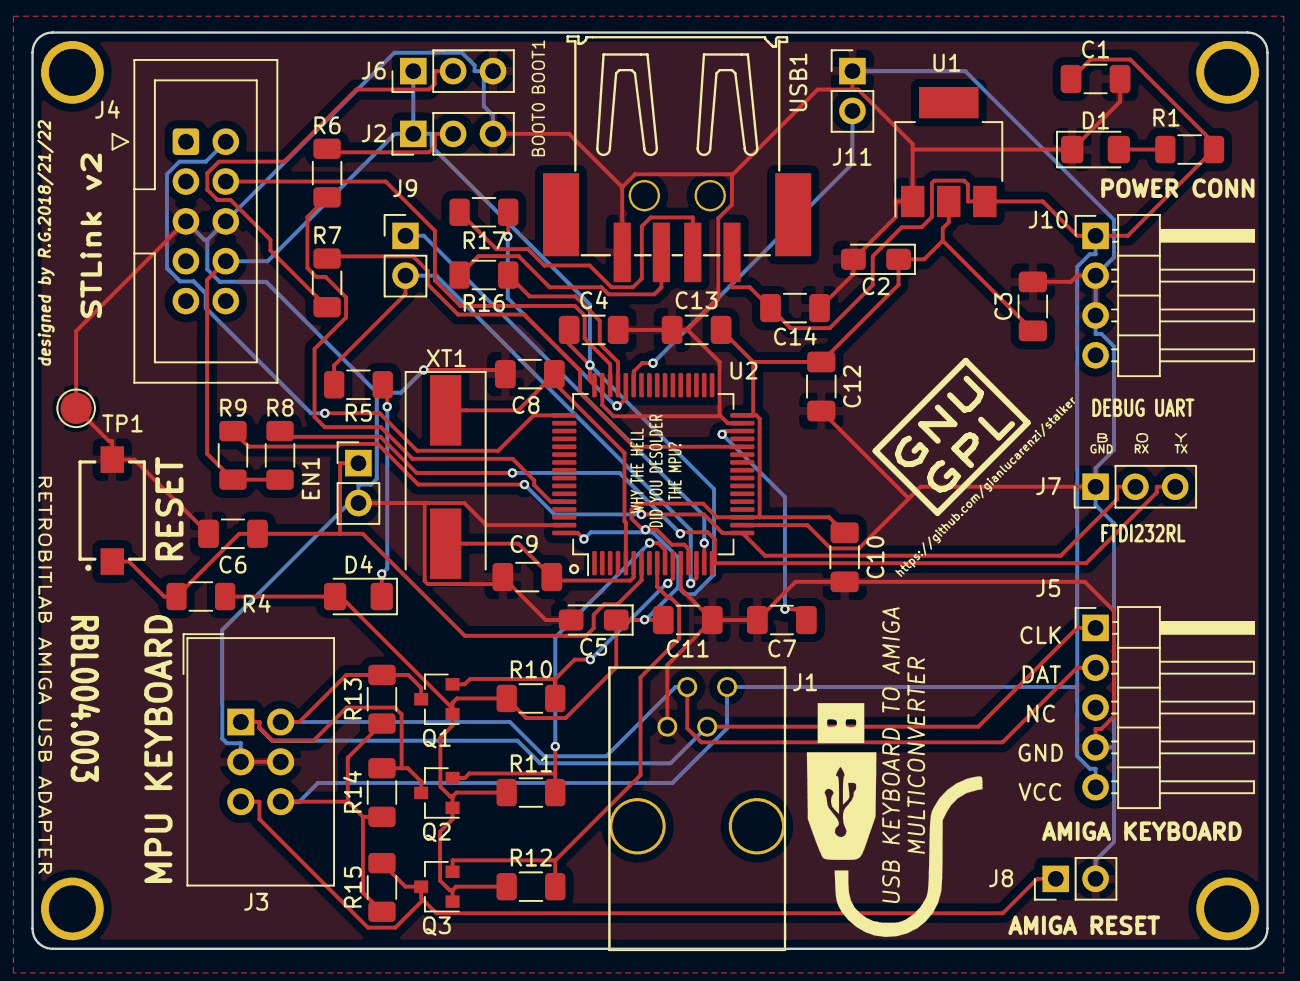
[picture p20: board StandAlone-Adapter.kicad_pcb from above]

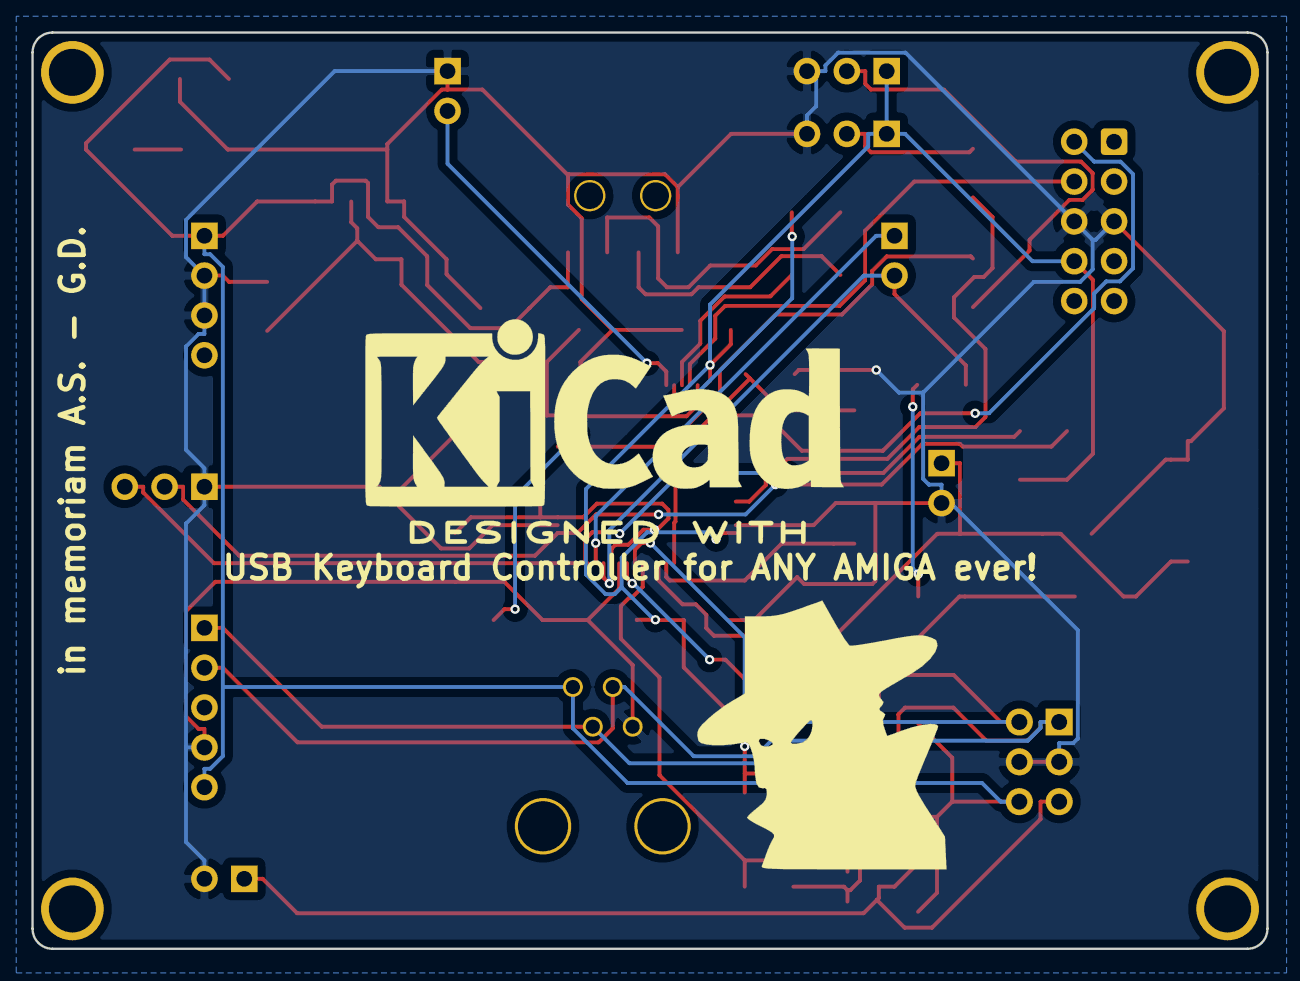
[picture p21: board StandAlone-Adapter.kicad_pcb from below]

Board: 2 copper layers, 78.7 x 58.4 mm, 60 parts (2 on the bottom side), 30 nets.

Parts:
C1: 100nF; C_1206_3216Metric_Pad1.33x1.80mm_HandSolder
C2: 10uF; CP_EIA-3216-12_Kemet-S_Pad1.58x1.35mm_HandSolder
C3, C4, C6, C10, C11, C12, C13, C14: 100n; C_1206_3216Metric_Pad1.33x1.80mm_HandSolder
C5: 10u; CP_EIA-3216-18_Kemet-A_Pad1.58x1.35mm_HandSolder
C7: 4.7uF; C_1206_3216Metric_Pad1.33x1.80mm_HandSolder
C8, C9: 22pF; C_1206_3216Metric_Pad1.33x1.80mm_HandSolder
D1, D4: RED; LED_1206_3216Metric_Pad1.42x1.75mm_HandSolder
EN1: CONN_01X02; PinHeader_1x02_P2.54mm_Vertical
H1, H2, H3, H4: CONN_01X01; MountingHole
J1: RJ10; RJ10-RECEPTACLE-Assmann-ASS-2004-3-4-LP-N-R
J2, J6, J7: Conn_01x03; PinHeader_1x03_P2.54mm_Vertical
J3: Conn_02x03_Odd_Even; IDC-Header_2x03_P2.54mm_Vertical
J4: JTAG SWDIO SWCLK; IDC-Header_2x05_P2.54mm_Vertical
J5: Conn_01x05; PinHeader_1x05_P2.54mm_Horizontal
J8, J9, J11: Conn_01x02; PinHeader_1x02_P2.54mm_Vertical
J10: Conn_01x04; PinHeader_1x04_P2.54mm_Horizontal
LOGO1: USB; USB_PLUG_15x15mm
LOGO2: GPL; KiCad-Logo2_12mm_SilkScreen
LOGO3: STALKER!; Symbol_GNU-GPL_SilkScreen_Small
LOGO4: Stalker Logo; Stalker_16.1x17.3mm
Q1, Q2, Q3: BSS138; SOT-23
R1, R5: 330R; R_1206_3216Metric_Pad1.30x1.75mm_HandSolder
R4, R6, R7, R8, R9, R10, R11, R12, R13, R14, R15: 10K; R_1206_3216Metric_Pad1.30x1.75mm_HandSolder
R16, R17: 22R; R_1206_3216Metric_Pad1.30x1.75mm_HandSolder
RESET1: SW_PUSH; SPST-7.3x3.9x2.5-WUERTH-434121025816
TP1: GND; TestPoint_Pad_D2.0mm
U1: AZ1117-3.3; SOT-223
U2: STM32F401RBTx; LQFP-64_10x10mm_P0.5mm
USB1: USB_A_SMD_LCSC; USB_A_M04P-F000_LCSC_C386738
XT1: 8Mhz; Crystal_SMD_HC49-SD

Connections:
+5V: C1.1, C14.2, J1.1, J3.6, J5.5, J10.1, R1.1, R13.1, R14.1, R15.1, U1.3, USB1.1
BOOT0: J2.2, R6.2
BOOT1: J6.2, R7.1
GND: C1.2, C2.2, C3.2, C4.2, C5.2, C6.1, C7.2, C8.2, C9.2, C10.1, C11.1, C12.1, C13.1, C14.1, D1.1, EN1.2, J1.4, J2.3, J3.3, J3.4, J4.5, J4.6, J5.4, J6.3, J7.1, J8.2, J10.2, J10.3, J11.1, RESET1.2, TP1.1, U1.1, U2.12, U2.18, U2.31, U2.47, U2.63, USB1.4
KBD_3v3_CLOCK: Q2.2, R11.2, U2.10
KBD_3v3_DATA: Q1.2, R10.2, U2.11
KBD_3v3_RESET: Q3.2, R12.2, U2.9
KBD_CLOCK: J1.2, J3.1, J5.1, Q2.3, R14.2
KBD_DATA: J1.3, J3.2, J5.2, Q1.3, R13.2
KBD_RESET: J3.5, J8.1, Q3.3, R15.2
NRST: C6.2, EN1.1, R4.1, RESET1.1, U2.7
unnamed: C7.1, U2.30
unnamed: C8.1, U2.5, XT1.1
unnamed: C9.1, U2.6, XT1.2
unnamed: D1.2, R1.2
unnamed: D4.1, R5.1
unnamed: R6.1, U2.60
unnamed: R7.2, U2.28
unnamed: R16.2, USB1.3
unnamed: R17.2, USB1.2
SWDCLK: J4.2, U2.49
SWDIO: J4.4, U2.46
TP1: J9.2, R5.2, U2.14
TP2: J9.1, U2.15
UART_RX_TTL: J7.2, R9.2, U2.17
UART_TX_TTL: J7.3, R8.2, U2.16
USB_ID: J11.2, U2.43
USB_N: R17.1, U2.44
USB_P: R16.1, U2.45
VCC3V3: C2.1, C3.1, C4.1, C5.1, C10.2, C11.2, C12.2, C13.2, D4.2, J2.1, J4.8, J6.1, Q1.1, Q2.1, Q3.1, R4.2, R8.1, R9.1, R10.1, R11.1, R12.1, U1.2, U2.13, U2.19, U2.32, U2.48, U2.64

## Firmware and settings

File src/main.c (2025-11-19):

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
/* Includes ------------------------------------------------------------------*/
#include "main.h"
#include "cmsis_os.h"
#include "usb_host.h"
#include <stdio.h>
#include <stdbool.h>
#include "assert.h"

/* USER CODE BEGIN Includes */
#include "log_task.h"
#include "delay_us.h"
#include "debug.h"
#include "usb_task.h"
#include "amiga.h"
#include "amiga_task.h"
#include "led_manager_task.h"
#include "eeprom_task.h"
/* USER CODE END Includes */

UART_HandleTypeDef huart2;

/* Definitions for USBKeyBoardTask */
osThreadId_t USBKeyBoardTaskHandle;
const osThreadAttr_t USBKeyBoardTask_attributes = {
	.name = "USBKeyBoardTask",
	.stack_size = 1024,  // Increased from 512 to 1024 for new functionality
	.priority = (osPriority_t) osPriorityNormal,
};
/* Definitions for AmigaTask */
osThreadId_t AmigaTaskHandle;
const osThreadAttr_t AmigaTask_attributes = {
	.name = "AmigaTask",
	.stack_size = 1024,  // Increased from 512 to 1024
	.priority = (osPriority_t) osPriorityLow,
};
/* Definitions for LedManagerTask */
osThreadId_t LedManagerTaskHandle;
const osThreadAttr_t LedManagerTask_attributes = {
	.name = "LedManagerTask",
	.stack_size = 512,
	.priority = (osPriority_t) osPriorityLow,
};

/** @brief Global queue handle for keyboard data communication (USB -> Amiga) */
osMessageQueueId_t keyboardQueueHandle;
const osMessageQueueAttr_t keyboardQueueHandle_attributes = {
	.name = "keyboardQueue"
};

/** @brief Current keyboard mode (AMIGA_MODE or PC_MODE) */
volatile reset_keypress_mode_t current_mode = AMIGA_MODE;

/** @brief Global queue handle for LED status communication (Amiga -> USB) */
osMessageQueueId_t ledQueueHandle;
const osMessageQueueAttr_t ledQueueHandle_attributes = {
		.name = "ledQueue"
};

/** @brief Global queue handle for LED manager commands */
osMessageQueueId_t ledManagerQueueHandle;
const osMessageQueueAttr_t ledManagerQueueHandle_attributes = {
		.name = "ledManagerQueue"
};

/** @brief Global queue handle for internal amiga task messages */
osMessageQueueId_t amigaTaskQueueHandle;
const osMessageQueueAttr_t amigaTaskQueueHandle_attributes = {
		.name = "amigaTaskQueue"
};

/* USER CODE BEGIN PV */

static int debuglevel = DBG_INFO;
/* USER CODE END PV */

void SystemClock_Config(void);
static void MX_GPIO_Init(void);
static void MX_USART2_UART_Init(void);


/* USER CODE END 0 */

/** @brief Firmware build version string with timestamp */
static const char *fwBuild = "v3.1NG-RTOS BUILD: " __TIME__ "-" __DATE__;
/**
  * @brief  Display startup banner with firmware information
  * @details Prints colorized banner with firmware version and build information
  *          to the debug UART. Includes optional Amiberry easter egg message.
  * @param  None
  * @retval None
  */
static void banner(void)
{
	printf("\r\n\r\n" ANSI_BLUE "RETROBITLAB AMIGA USB KEYBOARD ADAPTER V2" ANSI_RESET "\r\n");
#ifdef __AMIBERRY_EASTER_EGG__
	printf(ANSI_LIGHT_MAGENTA "Amiberry Dimitris Panokostas VERSION" ANSI_RESET "\r\n");
#endif
	printf(ANSI_YELLOW);
	printf("FWVER: %s", fwBuild);
	printf(ANSI_RESET "\r\n");
	printf("\r\n\n");
}

static void create_system_queues(void)
{
	/* creation of usbLedQueue */
	ledQueueHandle = osMessageQueueNew (16, sizeof(led_message_t), &ledQueueHandle_attributes);
	if (ledQueueHandle == NULL)
	{
		DBG_E("Error Creating ledQueueHandle\r\n");
		assert(ledQueueHandle == NULL);
	}
	else
	{
		DBG_V("ledQueueHandle created %p.\r\n", ledQueueHandle);
	}

	ledManagerQueueHandle = osMessageQueueNew (32, sizeof(led_manager_message_t), &ledManagerQueueHandle_attributes);
	if (ledManagerQueueHandle == NULL)
	{
		DBG_E("Error Creating ledManagerQueueHandle\r\n");
		assert(ledManagerQueueHandle == NULL);
	}
	else
	{
		DBG_V("ledManagerQueueHandle created %p.\r\n", ledManagerQueueHandle);
	}

	keyboardQueueHandle = osMessageQueueNew (16, sizeof(keyboard_message_t), &keyboardQueueHandle_attributes);
	if (keyboardQueueHandle == NULL)
	{
		DBG_E("Error Creating keyboardQueueHandle\r\n");
		assert(keyboardQueueHandle == NULL);
	}
	else
	{
		DBG_V("keyboardQueueHandle created %p.\r\n", keyboardQueueHandle);
	}

	amigaTaskQueueHandle = osMessageQueueNew (8, sizeof(AmigaTaskMsg_t), &amigaTaskQueueHandle_attributes);
	if (amigaTaskQueueHandle == NULL)
	{
		DBG_E("Error Creating amigaTaskQueueHandle\r\n");
		assert(amigaTaskQueueHandle == NULL);
	}
	else
	{
		DBG_V("amigaTaskQueueHandle created %p.\r\n", amigaTaskQueueHandle);
	}
	DBG_I("System Queues Created.\r\n");
}

static void create_system_tasks(void)
{
	/* creation of USBKeyBoardTask */
	USBKeyBoardTaskHandle = osThreadNew(usbKeyboardTask, NULL, &USBKeyBoardTask_attributes);
	if (USBKeyBoardTaskHandle == NULL)
	{
		DBG_E("Error Creating Task USBKeyBoardTaskHandle\r\n");
		assert(USBKeyBoardTaskHandle == NULL);
	}
	else
	{
		DBG_V("USBKeyBoardTaskHandle created %p.\r\n", USBKeyBoardTaskHandle);
	}

	/* creation of AmigaTask */
	AmigaTaskHandle = osThreadNew(amigaTask, NULL, &AmigaTask_attributes);
	if (AmigaTaskHandle == NULL)
	{
		DBG_E("Error Creating Task AmigaTaskHandle\r\n");
		assert(AmigaTaskHandle == NULL);
	}
	else
	{
		DBG_V("AmigaTaskHandle created %p.\r\n", AmigaTaskHandle);
	}

	/* creation of LedManagerTask */
	LedManagerTaskHandle = osThreadNew(LedManagerTask, NULL, &LedManagerTask_attributes);
	if (LedManagerTaskHandle == NULL)
	{
		DBG_E("Error Creating Task LedManagerTaskHandle\r\n");
		assert(LedManagerTaskHandle == NULL);
	}
	else
	{
		DBG_V("LedManagerTaskHandle created %p.\r\n", LedManagerTaskHandle);
	}
	DBG_I("System Tasks Created\r\n");
}

#define PANIC_BLINK_RATE 500000L
static void panic(void)
{
	int j;
	/* USER CODE END WHILE */
	HAL_GPIO_WritePin(LED_PIN_GPIO_Port, LED_PIN_Pin, GPIO_PIN_RESET);
	for(j=0; j < PANIC_BLINK_RATE; j++)
	{
		;;
	}
	HAL_GPIO_WritePin(LED_PIN_GPIO_Port, LED_PIN_Pin, GPIO_PIN_SET);
	for(j=0; j < PANIC_BLINK_RATE; j++)
	{
		;;
	}
}

/**
  * @brief  The application entry point.
  * @retval int
  */
int main(void)
{
	/* MCU Configuration--------------------------------------------------------*/
	/* Reset of all peripherals, Initializes the Flash interface and the Systick. */
	HAL_Init();

	/* Configure the system clock */
	SystemClock_Config();

	/* Initialize all configured peripherals */
	MX_GPIO_Init();
	MX_USART2_UART_Init();

	DelayUs_Init();
	LogTask_Init(&huart2);

	banner();

	DBG_I("Starting FreeRTOS-based USB to Amiga Keyboard Adapter Next Gen\r\n");

	/* Init scheduler */
	osKernelInitialize();

	/* USER CODE BEGIN RTOS_MUTEX */
	/* add mutexes, ... */
	/* USER CODE END RTOS_MUTEX */

	/* USER CODE BEGIN RTOS_SEMAPHORES */
	/* add semaphores, ... */
	/* USER CODE END RTOS_SEMAPHORES */

	/* USER CODE BEGIN RTOS_TIMERS */
	/* start timers, add new ones, ... */
	/* USER CODE END RTOS_TIMERS */

	/* Create the queue(s) */
	create_system_queues();

	/* USER CODE BEGIN RTOS_QUEUES */
	/* add queues, ... */
	/* USER CODE END RTOS_QUEUES */

	/* Create the thread(s) */
	/* Init and create the EEPROM management task */
	eeprom_task_init();

	create_system_tasks();

	/* Start scheduler */
	osKernelStart();

	/* We should never get here as control is now taken by the scheduler */
	DBG_E("#### Unexpected RTOS Kernel/System Failure ####\r\n");
	/* Infinite loop */
	/* USER CODE BEGIN WHILE */
	while (1)
	{
		/* USER CODE BEGIN 3 */
		panic();
		/* USER CODE END 3 */
	}
}

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
/**
  * @brief  Period elapsed callback in non blocking mode
  * @note   This function is called  when TIM1 interrupt took place, inside
  * HAL_TIM_IRQHandler(). It makes a direct call to HAL_IncTick() to increment
  * a global variable "uwTick" used as application time base.
  * @param  htim : TIM handle
  * @retval None
  */
void HAL_TIM_PeriodElapsedCallback(TIM_HandleTypeDef *htim)
{
  if (htim->Instance == TIM1)
  {
	HAL_IncTick();
  }
}

/**
  * @brief  This function is executed in case of error occurrence.
  * @retval None
  */
void Error_Handler(void)
{
  /* USER CODE BEGIN Error_Handler_Debug */
  /* User can add his own implementation to report the HAL error return state */
  printf("!!! Error_Handler called !!!\r\n");
  __disable_irq();
  panic();
  /* USER CODE END Error_Handler_Debug */
}

/* FreeRTOS stack overflow hook */
void vApplicationStackOverflowHook(TaskHandle_t xTask, char *pcTaskName)
{
  printf("!!! STACK OVERFLOW in task: %s !!!\r\n", pcTaskName);
  while(1);
}

/* FreeRTOS malloc failed hook */
void vApplicationMallocFailedHook(void)
{
  printf("!!! MALLOC FAILED - Heap exhausted !!!\r\n");
  while(1);
}
#ifdef USE_FULL_ASSERT
/**
  * @brief  Reports the name of the source file and the source line number
  *         where the assert_param error has occurred.
  * @param  file: pointer to the source file name
  * @param  line: assert_param error line source number
  * @retval None
  */
void assert_failed(uint8_t *file, uint32_t line)
{
  /* USER CODE BEGIN 6 */
  /* User can add his own implementation to report the file name and line number,
	 ex: printf("Wrong parameters value: file %s on line %d\r\n", file, line) */
  printf("Wrong parameters value: file %s on line %d\r\n", file, line);
  /* USER CODE END 6 */
}
#endif /* USE_FULL_ASSERT */

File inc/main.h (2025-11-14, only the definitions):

#define KBD_CLOCK_Pin       GPIO_PIN_2
#define KBD_CLOCK_GPIO_Port GPIOC
#define KBD_DATA_Pin        GPIO_PIN_3
#define KBD_DATA_GPIO_Port  GPIOC
#define KBD_RESET_Pin       GPIO_PIN_1
#define KBD_RESET_GPIO_Port GPIOC
#define TP1_Pin             GPIO_PIN_0
#define TP1_GPIO_Port       GPIOA
#define TP2_Pin             GPIO_PIN_1
#define TP2_GPIO_Port       GPIOA
#define LED_PIN_Pin         TP1_Pin
#define LED_PIN_GPIO_Port   TP1_GPIO_Port
#define DEBUG_TX_Pin        GPIO_PIN_2
#define DEBUG_TX_GPIO_Port  GPIOA
#define DEBUG_RX_Pin        GPIO_PIN_3
#define DEBUG_RX_GPIO_Port  GPIOA
#define USB_DM_Pin          GPIO_PIN_11
#define USB_DM_GPIO_Port    GPIOA
#define USB_DP_Pin          GPIO_PIN_12
#define USB_DP_GPIO_Port    GPIOA
#define USBH_Port           GPIOA

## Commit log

2018-12-21 - From CVS Repo
    [stm32f4eval.cfg]
2018-12-22 Added the hw section
    [A1200MPU-Adapter-BOM.ods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]
2018-12-22 Modified Library for RJ10 and USB A Host Connectors. Corrected Back Silk Stuff
2018-12-22 Modified for USB Host A and RJ10 Connectors
    [StandAlone-Adapter-B.Cu.gbl, StandAlone-Adapter-B.Mask.gbs, StandAlone-Adapter-B.Paste.gbp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]
2018-12-23 Modified for new import in github
    [A1200MPU-Adapter-B.Cu.gbl, A1200MPU-Adapter-B.Mask.gbs, A1200MPU-Adapter-B.Paste.gbp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]
2018-12-23 Added new capacitors filter on the Vcc line (backside)
    [A500MPU-Adapter-B.Cu.gbl, A500MPU-Adapter-B.Mask.gbs, A500MPU-Adapter-B.Paste.gbp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]
2018-12-23 Updated after Library Cleanup
    [A1200MPU-Adapter.sch, A500MPU-Adapter.sch, StandAlone-Adapter.sch]
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2018-12-31 The Debug UART Pins (RX & TX) were left unconnected
    [StandAlone-Adapter.kicad_pcb, StandAlone-Adapter.sch]
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2019-01-05 Cartridge & ECI Slots were reversed
2019-01-06 Changed to reflect new path on my system
    [StandAlone-Adapter.sch]
2019-01-20 Added all kicad libraries
    [StandAlone-Adapter.kicad_pcb, StandAlone-Adapter.sch]
2019-02-21 added filled zone and changed footprint for button reset
    [StandAlone-Adapter.kicad_pcb, StandAlone-Adapter.sch]
2019-02-28 modified for IDC Connector
    [StandAlone-Adapter-B.Cu.gbl, StandAlone-Adapter-B.Mask.gbs, StandAlone-Adapter-B.Paste.gbp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]
2019-03-01 Added the idc 2x3 box
    [A1200MPU-Adapter-B.Cu.gbl, A1200MPU-Adapter-B.Mask.gbs, A1200MPU-Adapter-B.Paste.gbp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]
2019-03-31 REfactoring for new Crystal Oscillator & new 1208 footprints handsoldering
    [StandAlone-Adapter-B.Cu.gbl, StandAlone-Adapter-B.Mask.gbs, StandAlone-Adapter-B.Paste.gbp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]
2019-03-31 Bill Of Material Added
    [StandAlone-Adapter.csv]
2019-03-31 Added Mouser's Bill of Material for 10 pcs. Just for reference for prices.
    [StandAlone-Adapter-Mouser-BOM.xls]
2019-04-01 Modified for better prices (10 pcs)
    [StandAlone-Adapter-Mouser-BOM.xls]
2019-04-01 BOM for 1pc (+ Shipping & Handling) BOM for 2pcs (no Shipping & Handling costs)
    [StandAlone-Adapter-Mouser-BOM_rev2_1pc.xls, StandAlone-Adapter-Mouser-BOM_rev2_2pcs.xls]
2019-04-12 Hide the LOGO label REF** on SilkScreen
    [StandAlone-Adapter.kicad_pcb]
2019-04-14 Modified for Capacitors & Added some boot options
    Replaced Electrolitic Capacitors with Tantalum ones. Added some
    capacitor as in the evaluation board schematics. Added BOOT1 pin. Added
    resistors for USB D+ D- lines. Increased the GND trace size to 0.35.
    [StandAlone-Adapter-B.Cu.gbl, StandAlone-Adapter-B.Mask.gbs, StandAlone-Adapter-B.Paste.gbp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]
2019-04-18 Modified some logo and silkscreen stuff
    [StandAlone-Adapter-B.Cu.gbl, StandAlone-Adapter-B.Mask.gbs, StandAlone-Adapter-B.Paste.gbp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]
2019-04-18 Added GNU GPL LOGO on silkscreen top
    [StandAlone-Adapter-B.Cu.gbl, StandAlone-Adapter-B.Mask.gbs, StandAlone-Adapter-B.Paste.gbp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]
2019-04-18 Bill Of Material (DigiKey)
    [StandAlone-Adapter-DIGIKEY.xls, StandAlone-Adapter.csv, StandAlone-Adapter.ods]
2019-04-18 Changed the capacitors for Crystal Oscillator. From 22pf to 20pf for 8Mhz
    [StandAlone-Adapter-B.Cu.gbl, StandAlone-Adapter-B.Mask.gbs, StandAlone-Adapter-B.Paste.gbp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]
2019-04-22 Hide GNU LOGO Text
    [StandAlone-Adapter.kicad_pcb]
2019-06-17 Added the single-board Bill-Of-Material from DigiKey.
    [StandAlone-Adapter-DIGIKEY-20190617.xls]
2019-06-17 Removed unused Library (Memory Controller)
    [StandAlone-Adapter.sch]
2019-06-22 Corrected. I do not have time to check what is really changed
    [StandAlone-Adapter-DIGIKEY.xls]
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2019-06-22 Added check for reset when idle...
    [amiga.c]
2019-06-22 Added a check for CLOCK line for external reset. 500msec of low means RESET!
    [main.c]
2019-06-23 Corrected comments. Renamed TP1 pin functions to led_
    [main.c]
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2019-09-07 Modified footprint of RJ10 (it was reversed)
    [StandAlone-Adapter-B.Cu.gbl, StandAlone-Adapter-B.Mask.gbs, StandAlone-Adapter-B.Paste.gbp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]
2019-09-14 Revert "Modified footprint of RJ10 (it was reversed)"
    This reverts commit 65f5b3a9598e76c611fb4c453a8e3fe395b7212b.
    [StandAlone-Adapter-B.Cu.gbl, StandAlone-Adapter-B.Mask.gbs, StandAlone-Adapter-B.Paste.gbp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]
2019-09-14 Modified for the correct layout of RJ10. Added some silkscreen labels
    [StandAlone-Adapter-B.Cu.gbl, StandAlone-Adapter-B.Mask.gbs, StandAlone-Adapter-B.Paste.gbp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]
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2021-04-16 From Kicad 4 to Kicad 5 update
    [StandAlone-Adapter-2021-04-14-13-59-44.sch, StandAlone-Adapter-2021-04-14-14-08-48.sch]
2021-04-16 From Kicad 4 to Kicad 5
    [StandAlone-Adapter-B_Cu.gbl, StandAlone-Adapter-B_Mask.gbs, StandAlone-Adapter-B_Paste.gbp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]
2022-10-13 Added a configuration for Amiga Reset. We can have a lot of Amiga reset keystrokes! LCTRL + LAMIGA + RAMIGA (standard) [ LGUI + RGUI ] LCTRL + LALT + RALT LCRTL + LALT + DEL (PC Standard) LCTRL + RAL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
    [amiga.c]
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2022-11-02 Removed Amiga (C)opyrighted stuff
    [StandAlone-Adapter.kicad_pcb]
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2022-11-04 Updated table for USB SCANCODES to AMIGA SCANCODES using: https://wiki.amigaos.net/wiki/Keymap_Library Added LCTRL for RESET checking
    [amiga.c]
2022-11-07 First import for LCSC PCB Production and components placement
    [StandAlone-Adapter.dsn, StandAlone-Adapter.kicad_pcb, StandAlone-Adapter.sch]
2022-11-07 All components are SMD for a easier PCB production (LCSC and others) The jumper headers are optionals, so it will be soldered if needed. The programming tool STLINK_V2 will have a special programming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
    [StandAlone-Adapter-B_Cu.gbl, StandAlone-Adapter-B_Mask.gbs, StandAlone-Adapter-B_Paste.gbp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]
2022-11-08 Sent to JLCPCB for quotes of 25 pcs and 100 pcs.
    [StandAlone-Adapter-B_Cu.gbl, StandAlone-Adapter-B_Mask.gbs, StandAlone-Adapter-B_Paste.gbp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]
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2022-11-08 Done by KiJLC plugin of PCBNEW
    [StandAlone-Adapter_bom_bot.csv, StandAlone-Adapter_bom_top.csv]
2022-11-09 Modified the JTAG STLinkV2 programmer port
    [StandAlone-Adapter.dsn]
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2022-11-10 For JLCPCB and LCSC Production
    [A1200MPU-Adapter_cpl_bot.csv, A1200MPU-Adapter_cpl_top.csv]
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2022-11-15 Added comments and swap tabs with spaces
    [main.c]
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2022-11-29 Updated PWR_FLAGs and other symbols
    [A600MPU-Adapter.kicad_pcb, A600MPU-Adapter.sch]
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2022-11-30 Gerber for JLCPCB/PCBWay Production run
    [A500MPU-Adapter-B_Cu.gbl, A500MPU-Adapter-B_Mask.gbs, A500MPU-Adapter-B_Paste.gbp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]
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2022-11-30 Generated for TOP & BOTTOM placement
    [A500MPU-Adapter_bom_bot.csv, A500MPU-Adapter_bom_top.csv]
2022-12-07 Smaller D1 silkscreen reference
    [A600MPU-Adapter-B_Cu.gbl, A600MPU-Adapter-B_Mask.gbs, A600MPU-Adapter-B_Paste.gbp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]
2023-01-21 Added STALKER-STAND-ALONE Digikey Shooping-Cart Bill Of Material
    [digikey-shopping-cart-STALKER-BOARD-TPH.ods]
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2023-02-15 Modified RCC HSE setup as the CubeMX seems to have a bug, when calculating the clock resources the very first time. Change some of the divisors and resolve-the-issue works. :-/ It (should) works with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
    dfu-util --download build/stm32f401-usb-keyboard-amiga.bin --alt 0 --dfuse-address 0x08004000
    If does not work, change --alt 0 up to the numbers the system will gives you when invoking with --list option.
    [main.c]
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2024-01-16 Updated for new interface
    [stm32f4eval.cfg]
2025-09-22 The reset check is valid only if the Amiga Reset Line stays low for more than 500msec (50 calls of 10msec)
    [amiga.c]
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2025-10-11 demo FreeRTOS runs. Now port every working code into stalker main
    [stm32f4eval.cfg]
2025-10-13 Removed. It should not be needed anymore
    [stm32f4eval.cfg]
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2026-02-18 Corrected F.Silkscreen for MPU U13 6570. Thanks to Pietro Colombo for pointing that issue
    [A600MPU-Adapter.kicad_pcb]
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2026-02-18 V3 RBL007.002 - Corrected F.Silkscreen for MPU U13 6570. Thanks to Pietro Colombo for pointing that issue
    [A600MPU-Adapter-B_Cu.gbl, A600MPU-Adapter-B_Mask.gbs, A600MPU-Adapter-B_Paste.gbp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]
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2026-02-18 V3 RBL007.002 With TEARDROPS - Corrected F.Silkscreen for MPU U13 6570. Thanks to Pietro Colombo for pointing that issue
2026-02-19 Updated from Library. /IRQ is not tied at VCC anymore.
    [A1200MPU-Adapter.kicad_pcb, A1200MPU-Adapter.sch]
2026-02-19 Removed. Not needed anymore
    [A1200MPU-Adapter-B.Cu.gbl, A1200MPU-Adapter-B.Mask.gbs, A1200MPU-Adapter-B.Paste.gbp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]
2026-02-19 RBL V2 Updated from Library. /IRQ is not tied at VCC anymore.
    [A1200MPU-Adapter.sch]
2026-02-19 Updated the symbol and the positioning of the footprint in bottom layer. Now all signals are checked with PCBEXPLORER for A600 (June Bug version) They seem to be ok. Updated from library too.
    [A600MPU-Adapter.kicad_pcb, A600MPU-Adapter.sch]
2026-02-20 The symbol 6571 had the pins counter-clockwise. Now it should be corrected as seen as http://amigapcb.org/ Thanks to Pietro Colombo
    [A600MPU-Adapter-B_Cu.gbl, A600MPU-Adapter-B_Mask.gbs, A600MPU-Adapter-B_Paste.gbp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]
2026-10-25 firmware: fix inverted asserts, log truncation notice; bump to v3.2NG-RTOS
    - main.c: queue/task creation asserts were inverted (assert(x == NULL)
    inside if (x == NULL)), so failures were never caught
    - ee.c: fix doubleWord -> double_word typo in the DOUBLEWORD flash path
    - log_task.c: report truncated log_printf messages with their original
    length, sent directly to the log queue without going through printf
    - usb_task.c: report failed queue puts; successful reset event is now
    verbose instead of an error
    - Firmware version v3.2NG-RTOS
2026-10-25 bootloader v1.1: clean hand-off to DFU ROM and application; update binaries
    - Bootloader: before jumping, deinit USART2, restore the default clock
    tree (HSI, PLL off), stop SysTick and clear NVIC enables/pending.
    The ST ROM DFU bootloader expects reset-like clocks, and the app no
    longer depends on the bootloader using the same PLL settings.
    GPIOs are left as-is so the Amiga stays in reset during updates.
    - Bootloader: remap System Memory at 0x0 before entering DFU ROM
    - Bootloader version 1.1
    - firmware/stm32f401-usb-keyboard-amiga.hex: v3.2NG-RTOS (was v1.3)
    - stalkb-bootloader/firmware: rebuilt v1.1 .hex/.elf
2026-10-29 hw: drop the missing PLCC-44 3D model from the MPU adapters
    Package_LCC.3dshapes/PLCC-44_THT-Socket.wrl does not exist in any KiCad
    version; the RetroBitLab 54020-44030LF model already shows the socket.
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

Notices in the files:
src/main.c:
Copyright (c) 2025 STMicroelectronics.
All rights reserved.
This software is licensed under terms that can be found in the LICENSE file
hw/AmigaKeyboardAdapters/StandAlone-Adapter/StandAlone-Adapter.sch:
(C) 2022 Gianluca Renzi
